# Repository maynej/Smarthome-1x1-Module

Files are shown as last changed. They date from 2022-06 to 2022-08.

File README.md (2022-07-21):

# Smarthome-1x1-Module

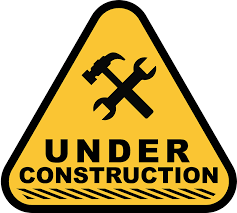
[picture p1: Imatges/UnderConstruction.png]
Maqueta de Casa Domótica Educativa en construcció 

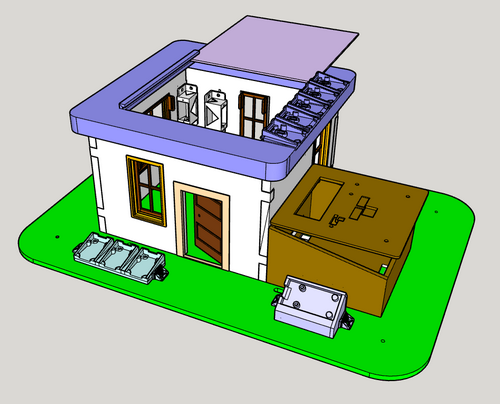
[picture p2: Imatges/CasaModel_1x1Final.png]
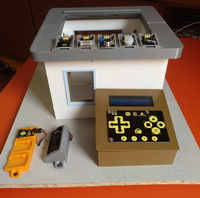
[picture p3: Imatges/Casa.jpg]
   

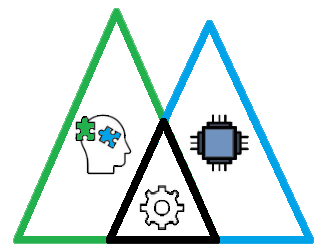
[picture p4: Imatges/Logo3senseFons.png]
Realitzada per [Jordi Mayné](https://github.com/maynej) des de Mechatronic Study jordi.mayne@mechatronicstudy.com 

L'objectiu es construir una casa modular abstreta del projecte del Parc mediambiental educatiu on permet provar diferents tecnologies de control aplicant la domòtica, gestionant el medi ambient i mesurant paràmetres de la natura.

Tota la [documentació es pot trobar en PDF](https://github.com/maynej/Smarthome-1x1-Module/tree/main/DOC). També estarà en llengua castellana (en preparació).

STL per imprimir [aquí](https://github.com/maynej/Smarthome-1x1-Module/tree/main/STL).

## Casa 3D 
  
Descripció         | Imatge          | Arxiu         
------------- | ------------- | ------------- 
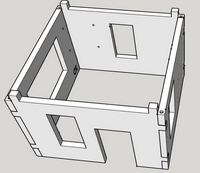
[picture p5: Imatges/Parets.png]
Parets | | [Parets](STL/Parets)
Finestres | | [Finestres](STL/Finestres)
Porta | | [Porta](STL/Porta)
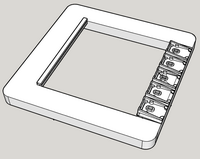
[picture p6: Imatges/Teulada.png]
Teulada | | [Teulada](STL/Teulada)
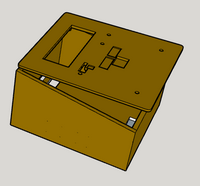
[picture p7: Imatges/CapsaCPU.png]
Capsa Control | | [Capsa CPU](STL/CPU)
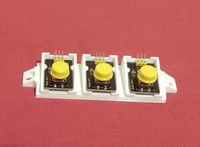
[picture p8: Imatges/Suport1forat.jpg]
Suport 1 forat | | [Suport 1 forat](STL/SuportsModuls/Suport1forat)
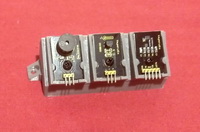
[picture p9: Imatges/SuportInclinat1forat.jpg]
Suport Inclinat 1 forat | | [Suport Inclinat 1 forat](STL/SuportsModuls/SuportInclinat1forat)
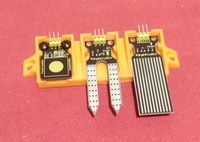
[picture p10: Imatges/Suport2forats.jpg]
Suport 2 forats | | [Suport 2 forats](STL/SuportsModuls/Suport2forats)
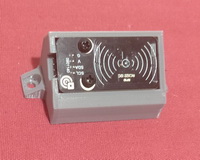
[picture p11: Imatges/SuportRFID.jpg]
Suport RFID | | [RFID](STL/SuportsModuls/SuportRFID.stl)

## Base de fusta  
  
Descripció         | Imatge          | Arxiu         
------------- | ------------- | ------------- 
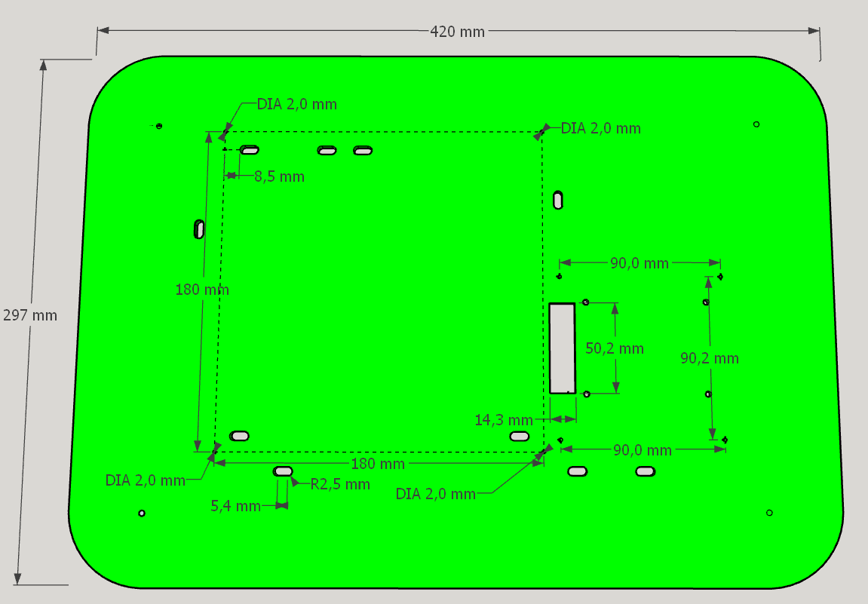
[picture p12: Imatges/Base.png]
Base fusta | | [Base fusta](Base/)

## Parets sólides
Descripció         | Imatge          | Arxiu         
------------- | ------------- | ------------- 
Parets | | [Parets](STL/Parets/ParetsSolidesOpcionals)

Creative Commons Attribution-NoComercial-ShareAlike 4.0 International (CC BY-NC-SA 4.0)  

## QR
QR Code generator

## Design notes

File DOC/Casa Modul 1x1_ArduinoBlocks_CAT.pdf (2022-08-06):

1 | JORDI MAYNE ‐ 2022

# Casa domòtica educativa

## Objectiu

Construir una maqueta d’una casa educativa per aplicar domòtica, mesurant paràmetres de la natura.

## Dinàmica educativa

- Es pretén que sigui Obert, Didàctic, Evolutiu, Modulable, Flexible, i de baix cost.
- La construcció de la maqueta està preparada per ser impresa en una impressora 3D convencional, però, es pot fer amb fusta o cartró ploma, i al ser modular permet adaptar‐la a les necessitats.
- Permet gestionar els llums a LED de colors, Sensors, Actuadors i altres elements electrònics per tal de fer la part de domòtica que es controlarà amb una placa ESP32 STEAMakers, encara que es pot fer amb una Arduino, Microbit o fins hi tot amb una Raspberry ...

Com es podrà veure en tota la descripció, es vol que es puguin explorar el màxim tipus d’elements i tecnologies.

## Descripció general

### Sensórica Externa

Mesurant el nostre entorn, com la Temperatura i Humitat ambient, Pressió atmosfèrica, Llum, Raigs ultraviolats, Qualitat del aire.

### Casa Domòtica

Control del màxim d’elements fent servir tecnologies diverses com la Llum, Accés, Ventilació, Calefacció, Motors.
Es pot detectar Gas, Foc, Llum, So, Humitat, Temperatura, Presencia (PIR, IR), Alarma.

### Comunicacions

Dintre d’un entorn sostenible les comunicacions son necessàries si es gestionen be com Bluetooth, Wifi, RFID

## Realització del projecte

- Descripció de cada part de la maqueta.
- Selecció de materials i components.
- Desenvolupament de cada part.
- Construcció de la maqueta.
- Composició del control electrònic.
- Control global de la maqueta.

### Maqueta

La maqueta es una abstracció d’una maqueta molt més gran, creada per poder aplicar molts més elements i controls, però, dintre del mon educatiu demanava una casa més apropiada, per el temps disponible durant el curs, per aplicar els conceptes i portar‐los a terme. Al ser modular permet adaptar‐la a les necessitats més escaients.

Casa Sostenible i Domòtica • Les noves cases han de ser sostenibles, aprofitant totes les energies renovables que estiguin a l’abast

(eòlica, tèrmica, solar, hidràulica, geotèrmica).
- Recollida de l’aigua pluvial per reaprofitar‐la.
- Aprofitament de la llum solar.
- Aïllament.
- Control de residus.
- Control domòtic.

En aquesta maqueta per espai no es poden portar a terme tots aquest punts, però, algun d’ells si.

### Disseny de la maqueta de la casa

Per fer aquesta maqueta he utilitzat un projecte molt més gran https://github.com/maynej/Smart‐Home i n’he fet una abstracció, ja que la seva modularitat ho permet, utilitzant un mòdul 1x1 permet tenir una maqueta tipus DIN A3 i a una escala 1:24 permet incloure i manipular els actuadors i sensors.

Es poden escollir de la casa gran les parets amb els formats que es vulguin, per cobrir les necessitats per aplicar la tecnologia. Es poden imprimir en una impressora 3D convencional de 220x220mm. Aquestes parets es poden modificar per adaptar‐les a un disseny propi, per això es mostren també parets sense cap porta ni finestra per si es vol desenvolupar un disseny propi. Les parets incorporen les fixacions dels actuadors a les portes, finestres, i en la teulada l’allotjament dels llums tant interiors com exteriors i en aquesta maqueta el suport per fixar els sensors. La teulada es pot treure molt fàcilment per manipular els components.

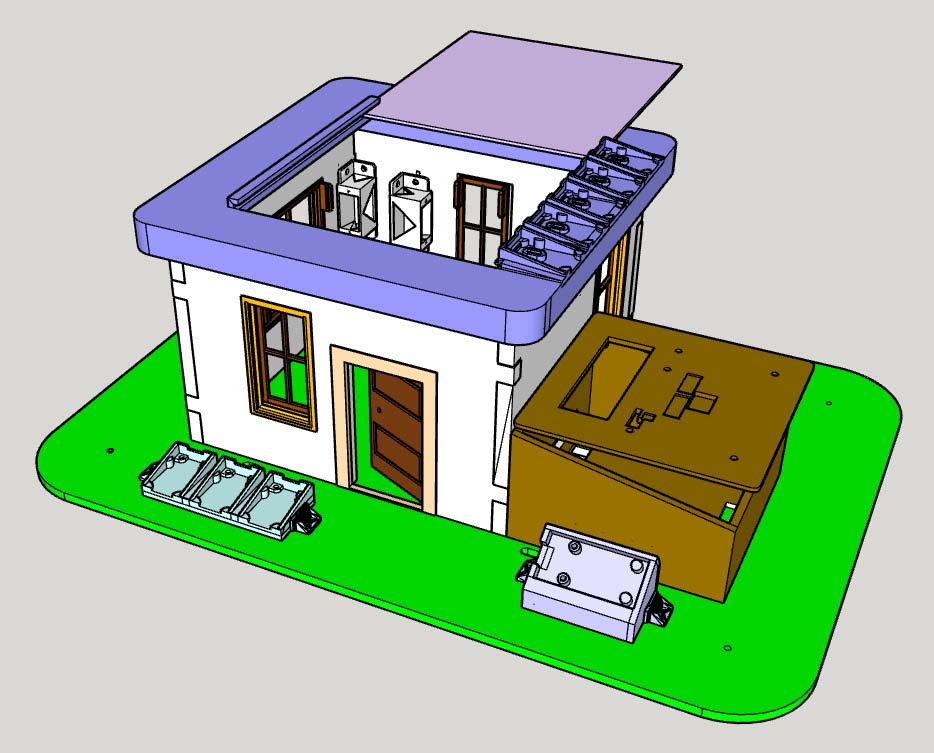
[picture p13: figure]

Altres suports com el mòdul de RFID, polsadors i d’altres sensors addicionals es poden fixar en la base, així com l’armari exterior (com si fos per guardar la fusta) que inclou la placa ESP32 STEAMakers, o Arduino Uno, un visualitzador LCD i un teclat tàctil.

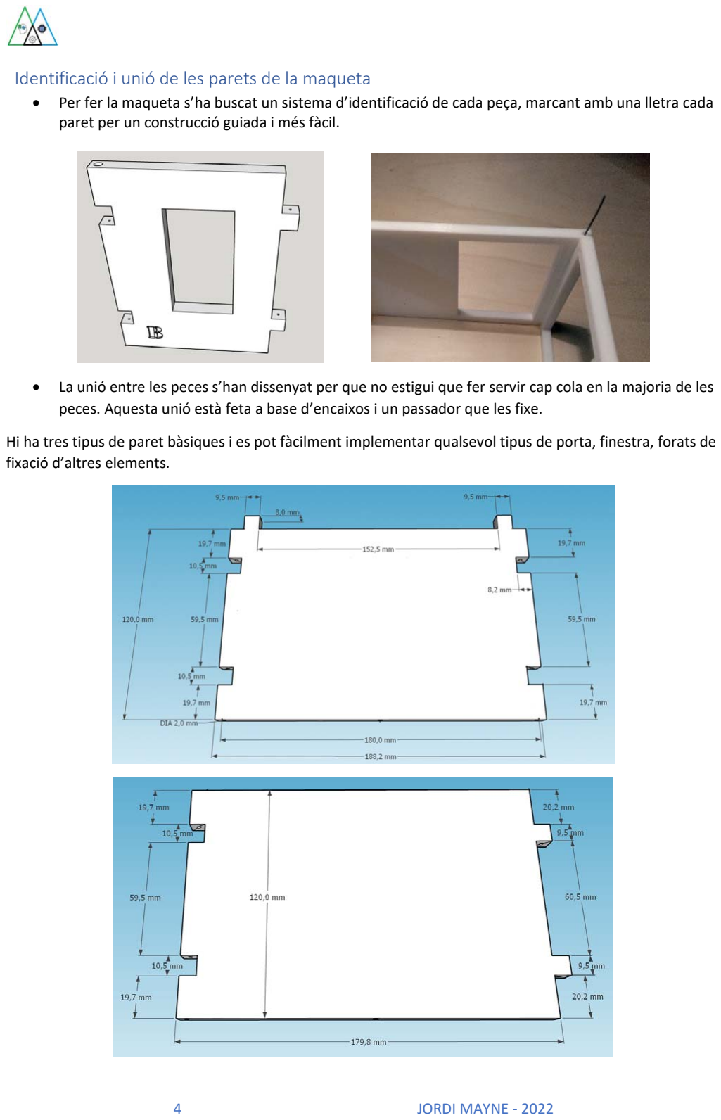
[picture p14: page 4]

### Identificació i unió de les parets de la maqueta

- Per fer la maqueta s’ha buscat un sistema d’identificació de cada peça, marcant amb una lletra cada paret per un construcció guiada i més fàcil.
- La unió entre les peces s’han dissenyat per que no estigui que fer servir cap cola en la majoria de les peces. Aquesta unió està feta a base d’encaixos i un passador que les fixe.

Hi ha tres tipus de paret bàsiques i es pot fàcilment implementar qualsevol tipus de porta, finestra, forats de fixació d’altres elements.

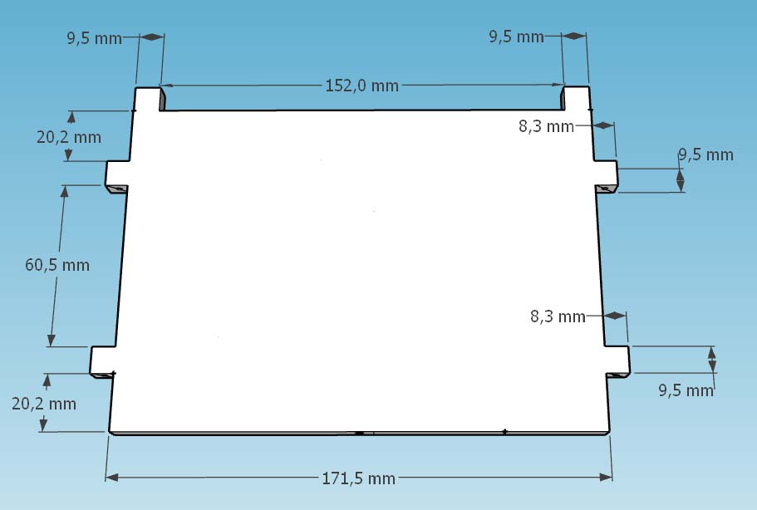
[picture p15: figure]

En aquest cas farem servir les parets A1, C1, T1 i H1.

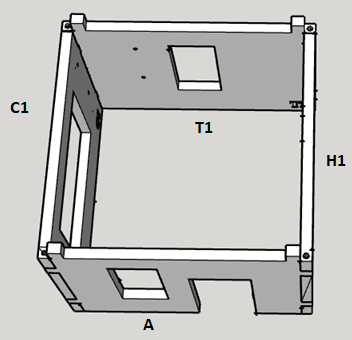
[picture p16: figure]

Alternativament la paret T1 es pot substituir per la T1_Fan que incorpora l’allotjament del ventilador de 40x40mm per simular la ventilació de la casa.

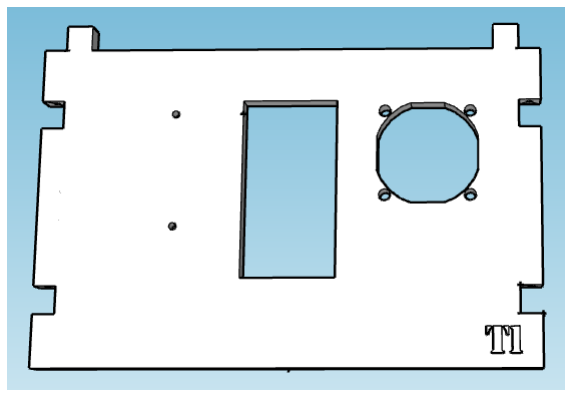
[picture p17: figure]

## Descripció de l’exterior Casa

- La casa es de tipus unifamiliar amb un sol habitacle amb una teulada amb sostre practicable permet que sigui accessible per manipular els diferents components.
- Porta d’accés a la casa. Timbre, i accés amb identificació per RFID.
- Il∙luminació a LED a color per l’exterior, amb detecció de presencia i de llum diürna.
- Els sensors en la teulada.

### Accés a la casa

Com qualsevol casa un polsador servirà de timbre, també un lector RFID identificarà i permetrà obrir la porta amb una targeta RFID vàlida.

- Timbre de trucada amb polsador (KS0029
- Lector RFID RC522 I2C (KS0205V2
- Porta motoritzada amb un servomotor SG90 (KS0194

### Il∙luminació de l’exterior de la casa

Llums LED de color WS2812 i un sensor de proximitat PIR (KS0052amb sensor de llum diürna per il∙luminar la porta d’entrada o les permanents de nit des del control central.

## Descripció de l’interior de la Casa

- Sistema d’alarma
- Control de llum LED individualitzat amb control d’intensitat de llum i de color
- Control finestres batents motoritzades
- Control de porta motoritzada
- Control Ventilació

### Llum interior de la Casa

El control de la llum es fa tant manualment, com automàtic mitjan sensors.

- LED + Sensor de moviment (KS0052
- LED + Polsador (KS0029
- LED + Sensor de veu (KS0035)
- LED + Sensor de llum ambiental TEMT6000 (KS0244 | o LDR (KS0028

### Ventilació

Un ventilador mou l’aire per tota la casa

- Temperatura LM35 (KS0022 | o DS18B20 (KS0023
- Humitat i Temperatura DTH11 (KS0034 | o SHT31 (KS0348
- Ventilador (KS0168

### Sistema d’Alarma

Un sistema integrat d’alarma contra intrusió, foc, gas

- Sensor de vibració (KS0037

- Sensor de cops (KS0024
- Sensor de gas MQ‐2 (KS0040
- Sensor flama (KS0036
- Brunzidor passiu (KS0019

### Pantalla i Teclat de control

- Pantalla LCD 2x16 I2C (KS0061, on es podrà mostrar dades de la casa. També es podrà tindre accés des de un telèfon o “tablet”.
- Teclat tàctil capacitiu (KS0210 | KS0260
- Monitorització de dades dels sensors.
- Monitorització del control d’accés a la casa, sistema de seguretat.
- Monitorització de la ventilació.

### Sistema central de control

El control també està pensat obert, si no ja no seria didàctic. Encara que es farà servir una ESP32 STEAMakers amb format Arduino UNO, està adaptat per utilitzar Arduino UNO, o Microbit.

El software d’aquestes plataformes permeten utilitzar diferents llenguatges de programació, Scratch, C++ per Arduino, ArduinoBlocks.

- Arduino UNO, STEAMakers ESP32: Arduino Blocks, C++

### Alimentació

La maqueta al igual que moltes cases actuals que generen energia per el autoconsum, necessiten també d’energia elèctrica addicional. La maqueta pot tindre generador d’energia que poden carregar unes petites bateries, com pot ser una plataforma de cèl∙lules solar però, normalment es farà servir una font d’energia a xarxa.

Plantejament de la casa Aquesta construcció es minimalista, però permet aplicar diferents tecnologies per el control i es poden canviar

o afegir sensors.

## Plantejament del control

- El control es podrà fer a través de tasques individualitzades o agrupades per anar progressant en el coneixement dels dispositius junt amb el visualitzador i teclat per mostrar el seus funcionaments.
- Moltes tasques es faran simulades intentant reproduir al màxim el seu funcionament real.
- Els sensors bàsics utilitzats es podran canviar per altres similars o més sofisticats, està previst que el seu accés i cablejat ho permeti.

### Maqueta de la casa

La casa s’ha format amb les següents peces, A, C1, T1, H1

### Finestres batents i Portes motoritzades

- Les finestres son batents amb moviment a través d’un servo‐motor.
- Les portes també estan motoritzades a través d’un servo‐motor.
- Totes les portes i finestres tenen els ancoratges en la paret per posar un servo‐motor.

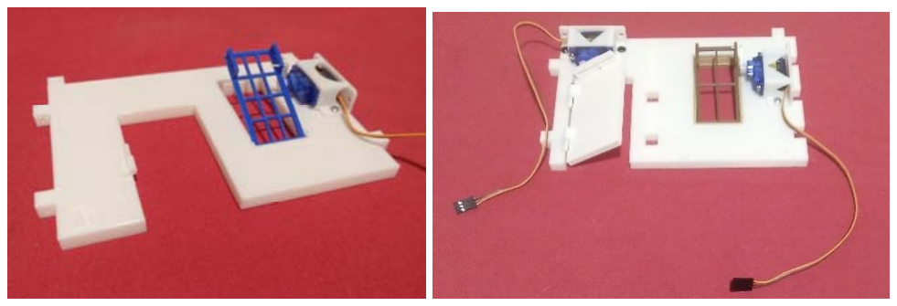
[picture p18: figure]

### Teulada

La teulada està formada per una sola peça, encara que es fa impresa amb dues parts si s’utilitza una base de 220x220mm. La base, per la part de sota, incorpora uns espais on aniran instal∙lades les llums externes envoltant la casa, així com la interna a LED a color del tipus tira de 8 LED WS2812. Amb sols tres fils es poden controlar tots els LED.

En la part superior es col∙locaran els sensors en uns suports, també permet posar una coberta semitransparent, per simular una entrada de llum solar, i per poder mesurar temperatura interior i exterior del habitacle.

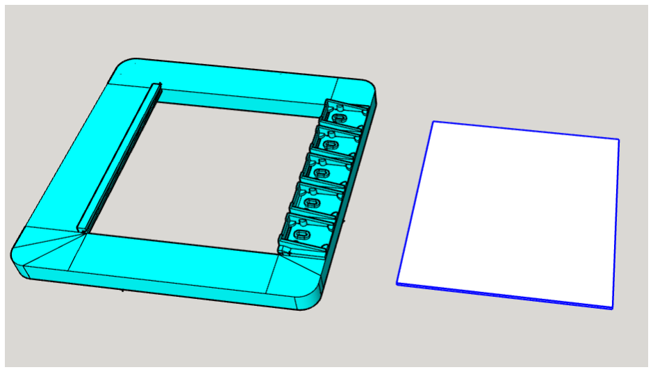
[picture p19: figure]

Teulada i coberta

### Subjecció de les parets a la base de fusta

Totes les parets tenen forats per ancorar‐les a la base de fusta de la casa.

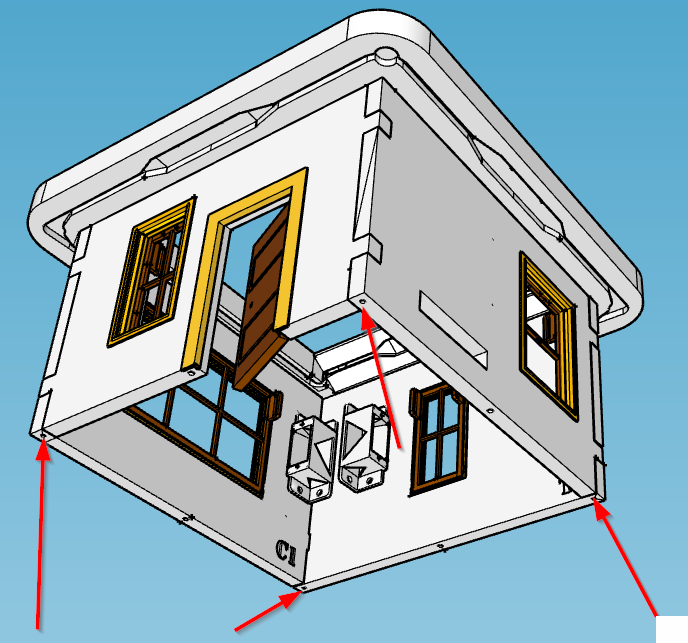
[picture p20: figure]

La base de fusta pot ser de 5mm, s’acota tota la maqueta i es mecanitza o es pot fer amb tall làser, s’inclou el fitxer svg. Es pot afegir en el dibuix svg el logo o nom del usuari.

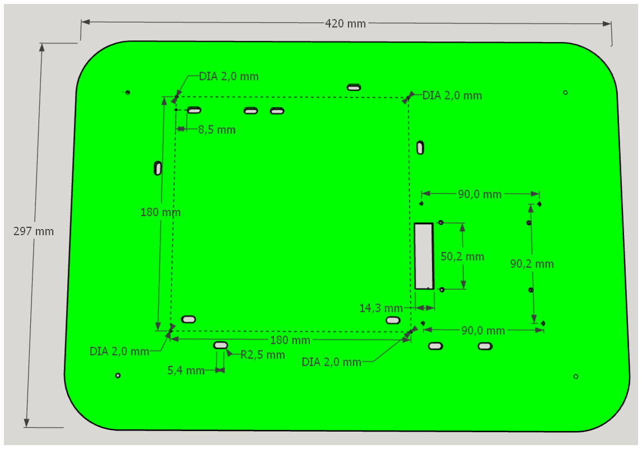
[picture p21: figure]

Els quatre punts de la casa fixen l’estructura, els forats ovalats son per el pas dels fils dels servomotors per sota de la base fins el pas rectangular per entrar en la capsa de control central.

Una vegada fixada l’estructura de la casa, es pot continuar treballant amb la resta de la casa, posant els marcs de les portes, finestres, ....

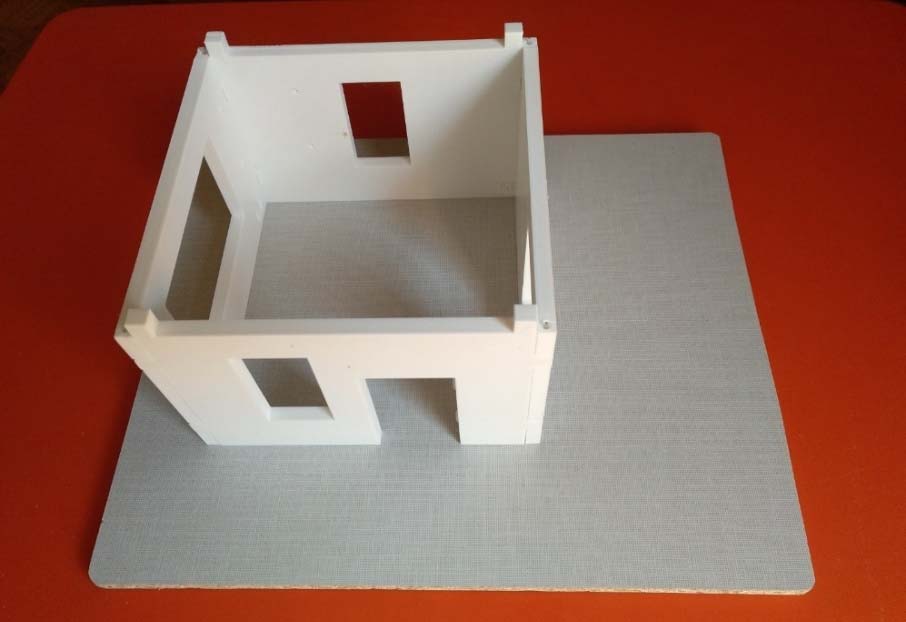
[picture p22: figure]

En el tauler base de la casa es fixen quatre separadors de goma de 20 mm d’alçada, suficient per deixar passar els cables.

La teulada semi‐transparent es pot fer amb full de plàstic a partir de 0,75mm de gruix per que tingui una mica de consistència. També les finestres també, però amb plàstic transparent.

### Muntatge electrònic

Per començar amb el sistema electrònic es pot fer el connexionat dels llums de LED multicolor WS2812B a la part inferior de la teulada. Es fan servir tres fils (Positiu 5V, negatiu (gnd) i dades) amb tres color ben diferenciats per no fer cap errada, es poden fixar els fils trenant en forma d’espiral i es poden subjectar amb tub termo‐retràctil.

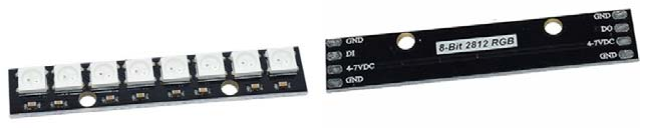
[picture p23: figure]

Les soldadures han d’estar ben fetes i que no es facin curt‐circuits en les connexions, cal fer una revisió visual i una prova de funcionament abans de col∙locar‐lo en les guies de la teulada.

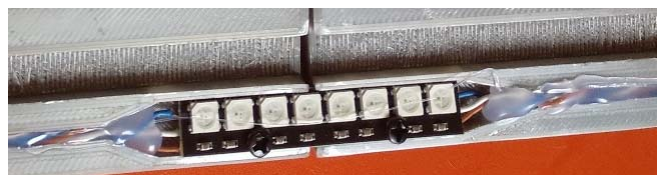
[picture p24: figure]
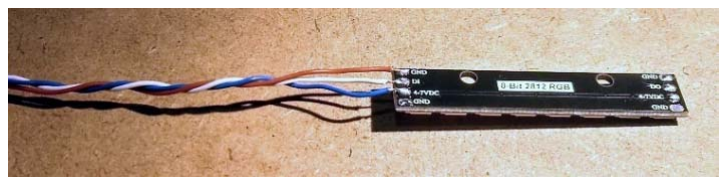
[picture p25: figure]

Una vegada que es te el cablejat fet i revisat, es col∙loca en la guia corresponent i es fixe amb una mica de cola termo‐fusible.

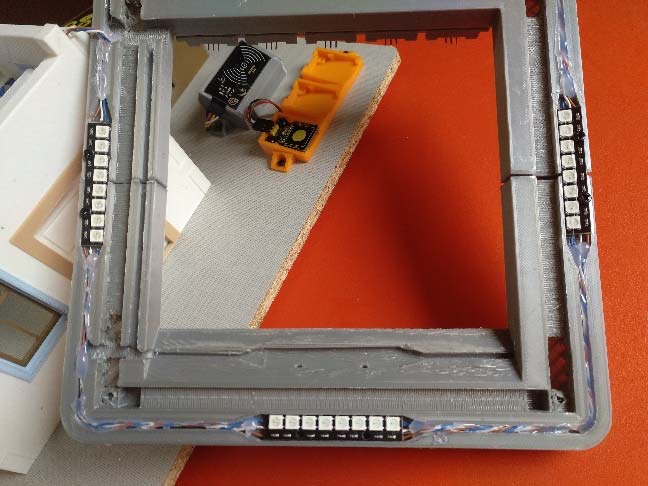
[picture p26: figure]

## Plantejament del control central

Tal com s’ha exposat al principi d’aquest document, el control central es podrà fer a través de tasques individualitzades o agrupades per facilitar una programació, primerament per parts per facilitar l’ús de un hardware senzill. D’aquesta manera es poden establir funcionalitats bàsiques fins les més complexes, i funcionalitats futures.

### Control central

El control central està plantejat utilitzant la placa STEAMakers, basada amb un controlador ESP32 Plus, compatible amb el format Arduino UNO, fabricada per Keyestudio, i ha estat desenvolupada conjuntament amb l’equip de Innova Didàctic.

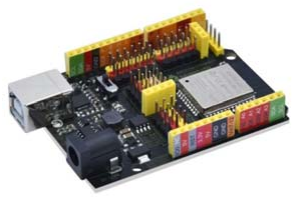
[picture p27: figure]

La primera cosa que sorprèn al veure aquesta placa es la quantitat de pins disponibles a banda dels connectors que incorporen totes les plaques Arduino, que corresponen a 12 entrades/sortides digitals, 4 entrades analògiques, 1 canal sèrie Tx/Rx i 5 connectors I2C, tots amb alimentació, i el sòcol per memòries µSD en la part posterior.

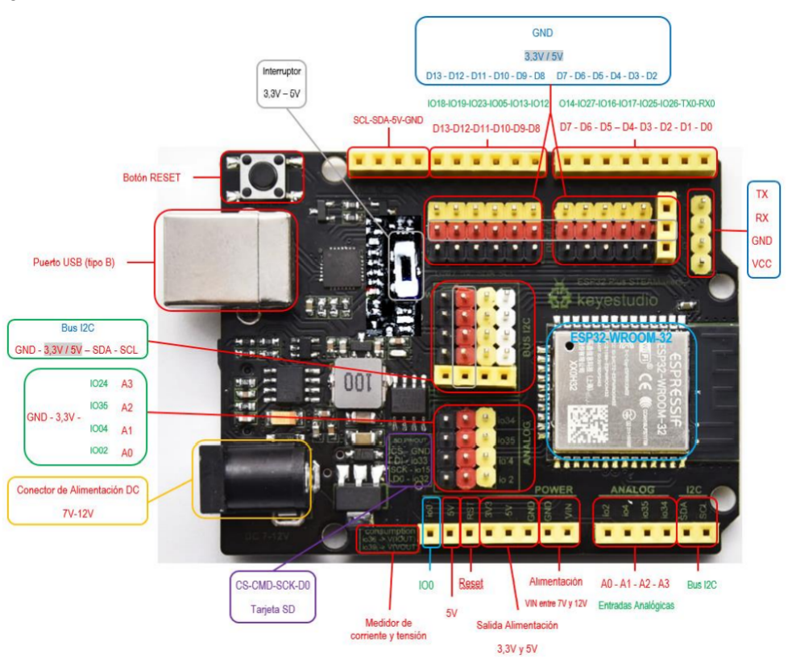
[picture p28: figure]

Però hi ha més detalls, un commutador de 3.3V a 5V per alguns pins d’alimentació i un shunt en l’alimentació per mesurar el corrent.

El processador ESP32 de 32 bit, és un sistema de doble nucli amb dues CPU (Unitat Central de Procés) amb arquitectura Harvard Xtensa LX6. Tota la memòria interna, la memòria externa i els perifèrics es troben en el bus de dades i/o en el bus d'instruccions d'aquestes CPU. Amb algunes excepcions menors, l'assignació d'adreces de les dues CPU és simètrica, el que significa que utilitzen les mateixes adreces per accedir a la mateixa memòria. Diversos perifèrics del sistema poden accedir a la memòria interna mitjançant DMA.
Les dues CPU s'anomenen "PRO_CPU" (per a computar els protocol) i "APP_CPU" (per computar l’aplicació), però, per a la majoria de propòsits, les dues CPU són utilitzables per qualsevol tasca. Més endavant es veurà en profunditat l’estructura del nucli.

### Tasques individualitzades

En aquest apartat es mostraran les tasques que es poden realitzar per treballar‐les individualment i el seu hardware associat.

### Control dels llums de la casa

Els llums de la casa son de LED del tipus RGB WS2812 (anomenats Neopixel) en format de tira de 8 LED, es poden encendre individualment amb el color i amb la intensitat de llum que es vulgui (per programa), i només amb tres fils. Això permet fer escenaris diferents de l’exterior de la casa, hi han quatre grups, una per cada paret. També hi ha una tira en el interior per poder crear un ambient de llum més càlida o més blanca. Aquets llums poden ser automàtics com el cas dels llums exteriors, amb un sensor de llum ambient, o a través de polsadors mecànics o tàctils. També es podrà comandar algun llum amb sensor de presencia. Per tant es una instal∙lació per un control molt flexible.

Primer de tot cal enumerar cada punt de llum de la casa per preparar la programació. Com que son grups de 8 LED i el primer correspon a la façana frontal (L1, L2, L3, L4, L5, L6, L7, L8). Si es fan servir més grups seran: L9‐L16 per la façana esquerra, L17‐L24 façana posterior, L25‐32 façana dreta i L33‐40 per la llum interior. També els polsadors, per encendre i apagar el llums interiors LINT i els llums exteriors LEXT.

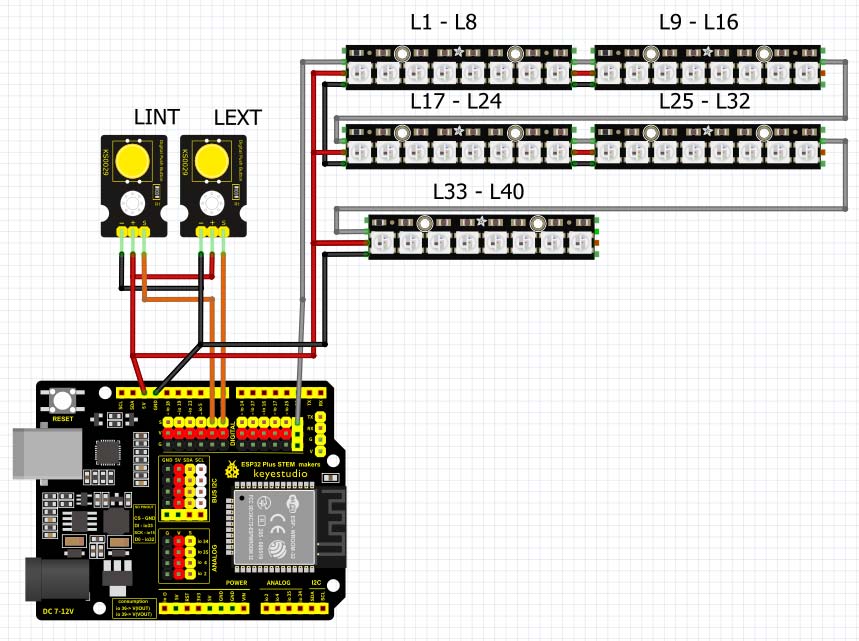
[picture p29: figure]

Es pot crear una taula per tenir tots els components:

Descripció | Actuador | Pin STEAMakers | Polsador | Pin STEAMakers
LED frontal | L1‐L8 | io12 | LEXT | io26
LED esquerra | L9‐L16 | io12 | LEXT | io26
LED posterior | L17‐L24 | io12 | LEXT | io26
LED dreta | L25‐L32 | io12 | LEXT | io26
LED interior | L33‐L40 | io13 | LINT | io26

Es a dir, es fan servir dos pins per els polsadors io12, io13, i per tots els LED només el pin io26. Ara afegirem el control de servos de porta i finestres.

### Control dels servos Porta i finestres

Els servos obren o tanquen porta i finestres, també cal enumerar cada un. Porta D1, finestra frontal W1, finestra esquerra W2, finestra posterior W3, finestra dreta W4.

Es pot crear una taula per tenir tots els components connectats a la placa STEAMakers:

Descripció | Actuador | Pin STEAMakers | Polsador | Pin STEAMakers
LED frontal | L1‐L8 | io12 | LEXT | io26
LED esquerra | L9‐L16 | io12 | LEXT | io26
LED posterior | L17‐L24 | io12 | LEXT | io26
LED dreta | L25‐L32 | io12 | LEXT | io26
LED interior | L33‐L40 | io13 | LINT | io26
Servo Porta frontal | S_D1 | io14 | D1 | io19
Servo Finestra frontal | S_W1 | io27 | W1 | io23
Servo Finestra esquerra | S_W2 | Io16 | W2 | io05
Servo Finestra posterior | S_W3 | io17 | W3 | io13
Servo Finestra dreta | S_W4 | io25 | W4 | io12
LED frontal | L1‐L8 | io26 | LEXT | io18
LED esquerra | L9‐L16 | io26 | LEXT | io18
LED posterior | L17‐L24 | io26 | LEXT | io18
LED dreta | L25‐L32 | io26 | LEXT | io18
LED interior | L33‐L40 | io26 | LINT | ?

Què ha passat? ..., que ens hem connectat tots els components menys un, el polsador de activació de la llum interior (LINT), no queda cap entrada/sortida digital lliure...

Encara que tots els LED tant exteriors com interiors només fan servir un sol pin (io26), els demés 6 polsadors ens ocupen la totalitat d’entrades digitals i encara ens en manca un.

Les solucions possibles son diverses, o fer servir menys finestres o afegir circuits que ens resoldran aquest problema.

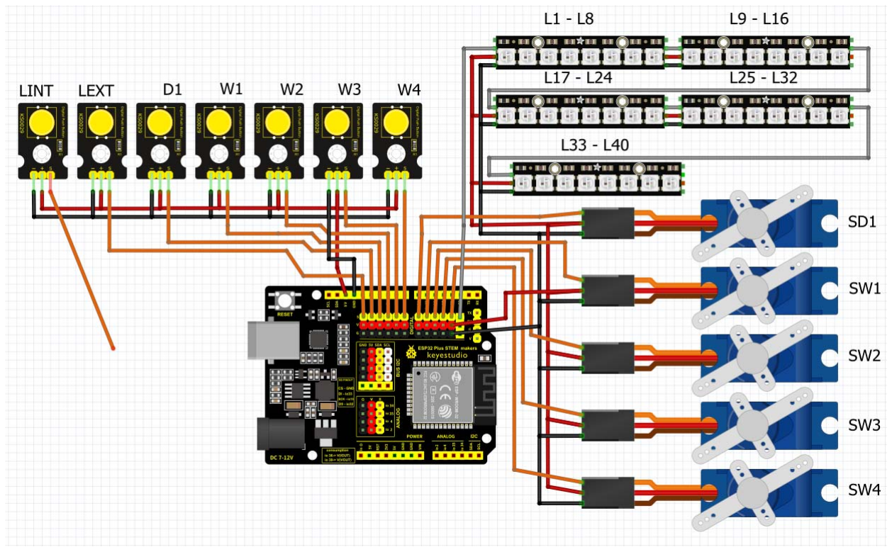
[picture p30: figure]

### Expansió d’entrades i sortides en un Arduino

Com que es necessiten moltes entrades de polsadors, cal plantejar utilitzar plaques Arduino que tenen més entrades/sortides o varies plaques Arduino connectades entre sí, cosa que no es la solució més adequada. Es millor col∙locar un expansor d’entrades/sortides amb un mòdul expansor via dos fils I2C.

PCF8574 es un mòdul expansor de 8 canals digitals de entrada/sortida amb comunicació I2C cap el microcontrolador, per defecte al alimentar el circuit son entrades digitals (P0 a P7), funciona entre 2,5 i 6V, incorpora 3 ponts (A0 a A2) per configurar l’adreça I2C (des de 0x20 a 0x27 si estan a ‐), te dos pins de comunicació típiques de I2C, SDA (dades), SCL (rellotge) i alimentació.

Es troben diferents formats de mòdul, aquest de color blau permet
expandir a més plaques PCF8574 encadenant diversos mòduls per tenir
encara més entrades/sortides digitals.

Cada nou mòdul addicional es configura amb una adreça I2C diferent, es selecciona amb els ponts de cada mòdul.

Aquest mòdul amb A0, A1 i A2 amb el pont a 0, correspon a l’adreça 0x20

Es poden encadenar diversos mòduls PCF8574 de la manera següent i canviant un pont d’adreçes.

Així quedarà el muntatge, alliberant 6 pins d’entrada de la placa STEAMakers, i encara ens queden dos pins lliures en el mòdul PCF8574.

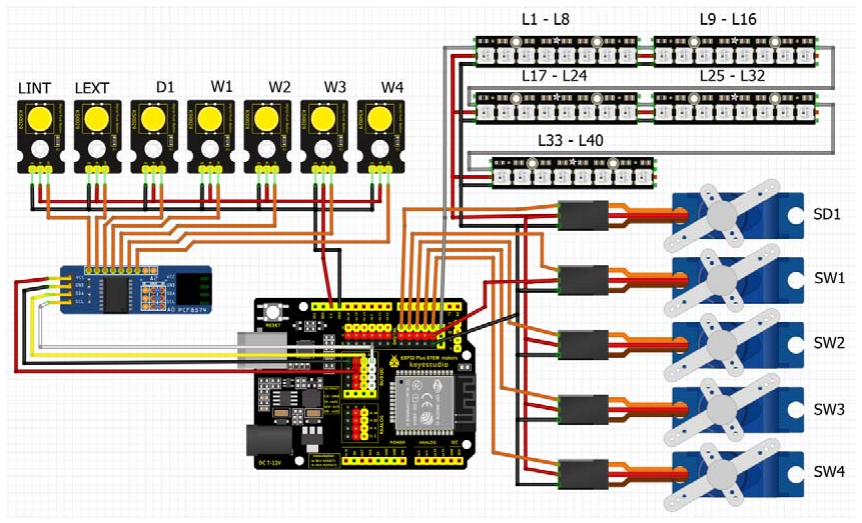
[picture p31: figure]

Si es volen alliberar més pins es pot fer afegint un altre mòdul I2C PCA9685 que suporta fins a 16 servomotors controlats via I2C. Disposa de pins per connectar adequadament els servomotors, les adreces I2C van des de 0x40 fins a 0x7F soldant els ponts (A0...A5), entrega 16 sortides PWM de 12 bits, s’alimenta a 5V, i les línies SDA i SCL de I2C son compatibles 3V3 o 5V.

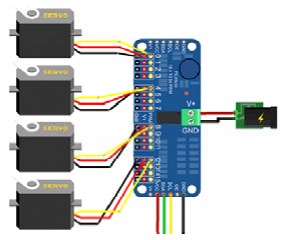
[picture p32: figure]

A banda de alliberar pins, s’ha de tenir en compte que els servomotors tenen
un consum “elevat”, sobre els 200mA que circula per dintre del circuit processador de Arduino i si a més alliberem aquesta corrent, sempre es millor, en aquest cas podem programar que les finestres s’obrin a la vegada, per airejar la casa, o tancar‐les per evitar que entri fred, 200mA multiplicat per 4 finestres son 0,8A que circularien per el circuit.

Servomotors SG90: Un servomotor, anomenat també servo, és un motor DC amb la capacitat de posar el seu eix en una posició o angle determinat, internament té una caixa d’engranatges reductora que fa augmentar el parell motor i redueix la velocitat, un
potenciòmetre està encarregat de sensar la posició de l’eix i junt amb una electrònica
formen un control de llaç tancat.

Hi ha diferents tipus de servo‐motors, el més utilitzat es el SG90 que es suficient per la majoria d’aplicacions. Funciona entre 3 i 7.2V, te un parell motor entre 1 i 1.6 kg/cm. Altres tenen parell motor més grans arribant fins a 15 kg/cm.

Utilitzant el mòdul PCA9685 allibera 5 pins més, digitals. Així queda l’esquema electric.

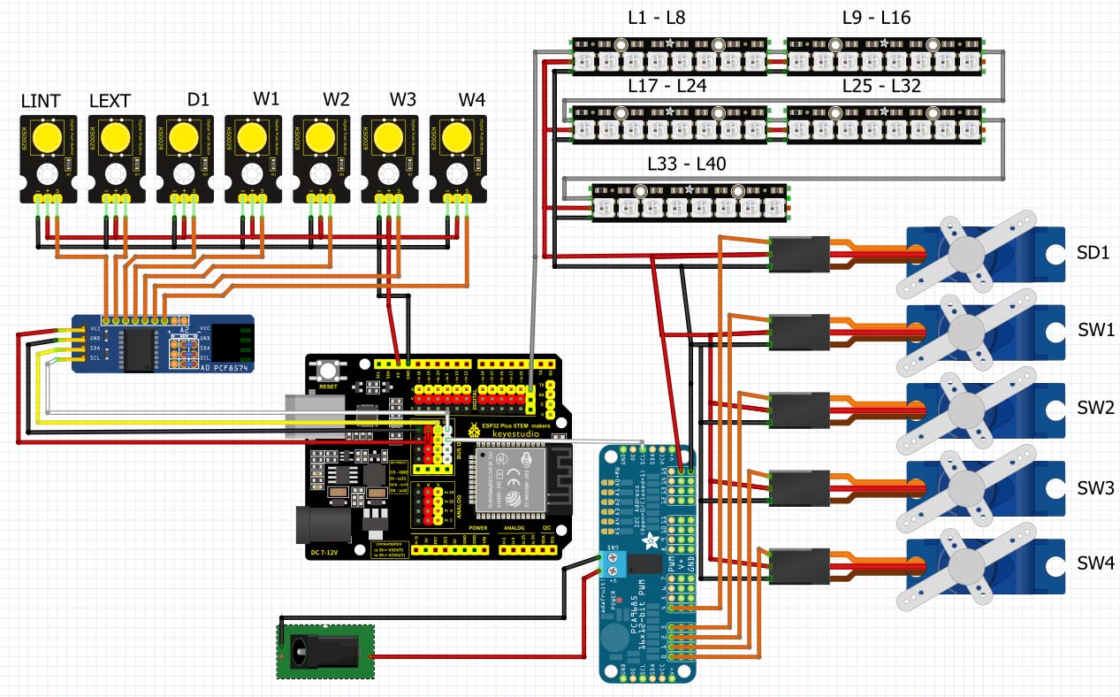
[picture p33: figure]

Anem afegint més components, visualitzador i teclat. Una vegada més s’ha escollit dos mòduls amb comunicació I2C visualitzador LCD 1602 (KS0061 i teclat tàctil TTP229 (KS0260.

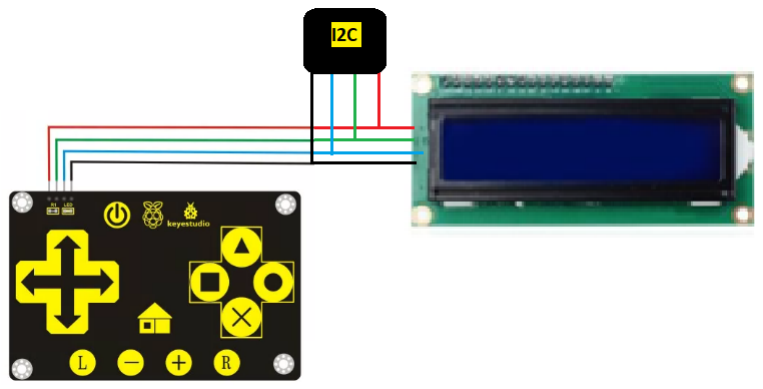
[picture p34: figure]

Amb aquests components no es fa servir cap pin digital

Per allotjar els mòduls STEAMakers, PCF8574 i PCA9685, així com el visualitzador LCD 1602 i el teclat TTP229, s’ha creat un armari per l’exterior de la casa. Es podrà fer servir tots aquests mòduls o no, però l’armari està preparat. La tapa pot allotjar el teclat TTP229 (KS0210 connector rectangular 6 pin i 3 forats de subjecció KS0260 connector 4 pin en línia més útil per fer servir els cables I2C i 4 forats de subjeccióla diferencia entre elles es el forats dels ancoratges i el tipus de connector, però la funcionalitat es la mateixa.

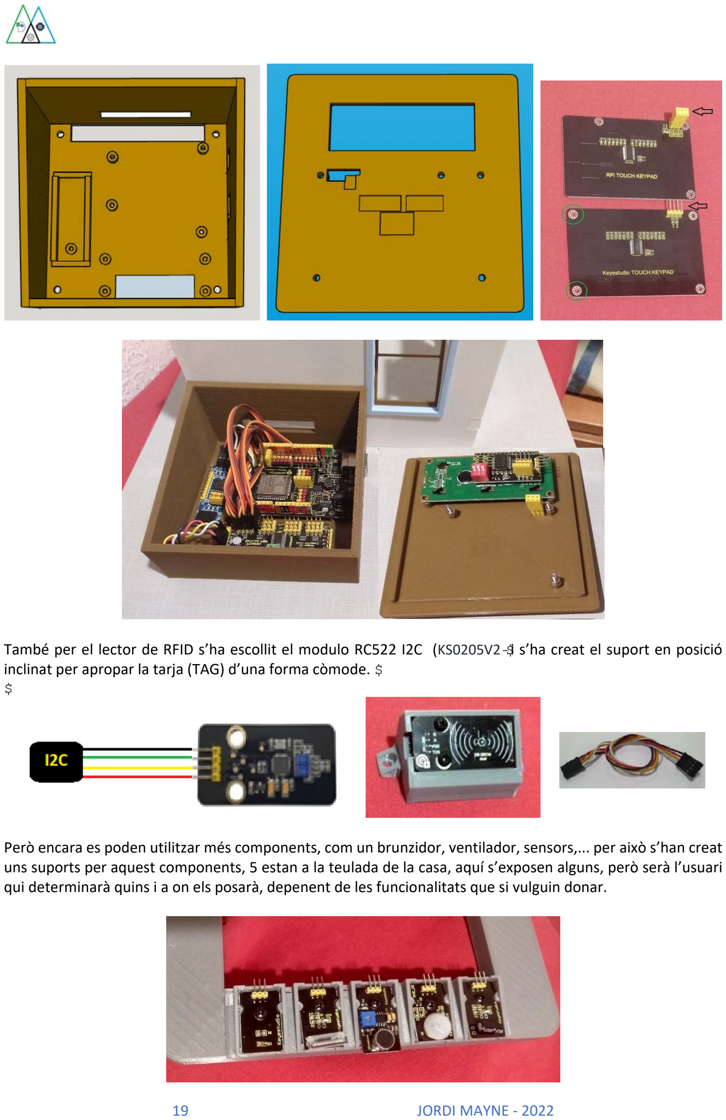
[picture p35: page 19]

També per el lector de RFID s’ha escollit el modulo RC522 I2C (KS0205V2i s’ha creat el suport en posició inclinat per apropar la tarja (TAG) d’una forma còmode.

Però encara es poden utilitzar més components, com un brunzidor, ventilador, sensors,... per això s’han creat uns suports per aquest components, 5 estan a la teulada de la casa, aquí s’exposen alguns, però serà l’usuari qui determinarà quins i a on els posarà, depenent de les funcionalitats que si vulguin donar.

Aquí es poden veure els diferents tipus de suports fins a 3 components, i en el repositori https://github.com/maynej/Smarthome‐1x1‐Module es poden trobar de 2, 3 i 4 components cada un. Keyestudio facilita bastant amb la uniformitat física de les plaques de cada component.

Brunzidor (KS0019(Buzzer en anglès) es un transductor electroacústic que produeix un so com si fos un altaveu, encara que en una qualitat menor. Serveix com un mecanisme
de senyalització o avis, i si s’utilitza en múltiples sistemes es pot que emeti sons diferents
segons la freqüència aplicada.

Pot servir, com a timbre de la porta, alarma de intrusió, o un altre tipus d’alarma dels diferents sensors que usem.

Sensors de presencia o moviment, hi ha diverses maneres de detectar “presencia”, el primer es conèixer els diferents tipus i veure que volem detectar, i a on. Es pot fer amb IR, ultrasons, PIR, làser, radar, mecànic, so.

IR consisteixen en un emissor i un receptor de IR actuen per rebot (KS0051 es bastant
direccional 35 graus, l’abast es de 2 a 40 cm (ajustable amb potenciòmetres), la
influencia dels rajos del sol van en contra.

Ultrasons, es tracta d’emetre un so a 40kHz (no audible per els humans) i rebre per rebot aquest so, mesurant el temps que tarda es pot determinar la distancia fins l’objecte. No es tan direccional (15 graus), l’abast es gran, entre 2 i 5m. (KS0206
Les aplicacions en una casa es poden ajustar gairebé a mesurar el nivell de líquid en
un dipòsit.

PIR (InfraRoig Passiu) es d’un material piroelèctric que canvia les seves propietats segons les emissions IR captades que passen a través d’una lent de Fresnel, que es una semiesfera que concentra aquestes emissions en un sol punt. Detecten objectes que emeten calor (com els cos humà i animals) l’abast es més gran fins a 3‐ 4 metres a 25ºC, i no es direccional 100 graus. Es el que farem servir per detectar quan una persona s’acosta a la porta i encenem el llum de la porta. (KS0052

Làser, realment ens referim als anomenats TOF (Time of Flight), son de darrera generació i mesuren el temps en que un pols de làser surt del emissor, rebota en el objecte i torna al receptor, es conta el temps i s’aconsegueix mesurar la distància amb molta precisió. Es molt direccional, l’abast pot arribar, depenent del model, fins a 2m (VL53L0X). Detecta qualsevol tipus d’objecte. En una casa el podríem fer servir per detectar que una persona s’acosta al intèrfon i es posa el sistema en marxa (per exemple, el vídeo porter).

Mecànic, podria ser un microruptor sota una fusta o en una porta(KS0021

Sensor de so, podem utilitzar el so de la veu per activar un llum, (KS0035)

Sensors de llum, hi ha una diversitat de sensors de llum, aquí ens centrem en el més bàsic basat en una LDR (Resistència que Depèn de la Llum) (KS0028 i el més complert i aconsellable, el sensor de llum ambiental TEMT6000 (KS0244.

El sensor TEMT6000 que només detecta la presència amalgamada de llum amb longituds d'ona en el rang de 390 a 700 nm, en altres paraules, no captarà infrarojos, ultraviolats o cap altra llum que no puguem veure directament. Es un sensor analògic que és sensible a l'espectre visible i es fa servir en molts aparells com smartphones, “tablets”, càmeres i està adaptat a la resposta de l’ull humà envers la llum. Te un angle de 60 graus i s’alimenta a 5V.
Aquí hi ha una taula de la il∙luminació típica de fonts comunes de llum visible:
Il∙luminació | Superfícies il∙luminades per
0.0001 lux | Cel nocturn ennuvolat i sense lluna
0.002 lux | Cel nocturn clar sense lluna amb resplendor del cel
0.27‐1.0 lux | Lluna plena en una nit clara
3.4 lux | límit fosc del crepuscle sota un cel clar
50 lux | llums de la sala d'estar familiar
80 lux | Passadissos, lavabos
100 lux | Dia molt fosc ennuvolat
320‐500 lux | Llum en una oficina
400 lux | Sortida o posta de sol en dies clars
1000 lux | Dia ennuvolat
10000‐25000 lux | Plena llum del dia (sol no directa)
32000‐100000 lux | Sol directe
Article de la Viquipèdia de Lux / CC BY

Ara que entenem una mica millor el funcionament del TEMT6000, es pot utilitzar en alguna cosa més interessant, com el control de llum exterior de la casa per que s'encengui i s'apagui automàticament, segons la llum ambient.

Sensor de humitat i temperatura, també hi ha una diversitat de sensors, individuals com el sensor de temperatura LM35 (KS0022 o el DS18B20 de millor qualitat (KS0023 o el que incorpora els dos sensors com el DTH11 (KS0034o el de més qualitat SHT31 (KS0348 que a més te comunicació I2C

LM35 | DS18B20 | DTH11 | SHT31

Aquests sensors poden estar ubicats en el interior de la casa i depenent dels valors es pot refrigerar o ventilar la casa es pot fer servir un ventilador adossat a una paret de la casa.

Com alternativa es pot utilitzar el ventilador (KS0168

El mateix sistema de sensors de humitat i temperatura es poden posar en el exterior de la casa, com una mini estació meteorològica.

Sistema d’alarma, amb diversos sensors es pot fer un sistema integrat d’alarma contra intrusió, foc, gas

El sensor de vibració (KS0037 |
sensor de cops (KS0024 | poden
detectar una intrusió.
El sensor de gas MQ‐2 (KS0040 |
ensor flama (KS0036 | poden
detectar alarma en una cuina.

## Programació de la casa

Com ja s’ha indicat aquest projecte es obert tant en la construcció i en el programari, sota una llicencia Creative Commons, on es poden aplicar diferents plaques i processadors amb moltes possibilitats. Però com sempre anirem pas a pas.

A més de preparar alguns exemples, aquesta maqueta precisament es per poder practicar programari i per tant qui vulgui “jugar” amb ella el millor es tenir la memòria buida i començar una programació des de cero, des de una part senzilla com encendre uns LED determinats, fer anar els servos per obrir o tancar una porta o finestra, o fer mesures amb els sensors. Però també depenent del nivell de la persona es pot fer un sistema complexa i global.

Es pot utilizar C per Arduino, Arduino Blocks o qualsevol altre IDE, però aquí veurem alguns exemples en Arduino Blocks, per la seva facilitat en l’aprenentatge i el suport a la placa STEMakers.

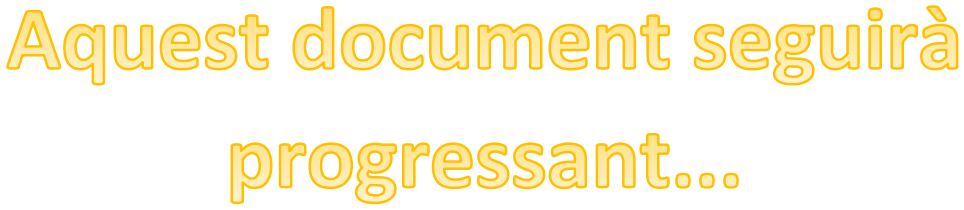
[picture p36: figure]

## Resum de peces impreses

- Parets Casa 4
- Marc i vidriera finestra gran 1 + 1
- Marc i vidriera finestra mitjana 1 + 1
- Marcs i vidrieres finestres petites 2 + 2
- Servos finestres + porta 5
- Porta + pom 1
- Teulada en dues meitats
- Suport RFID I2C 1
- Suport de 3 Polsadors 3
- Suport inclinat sensors 1
- Capsa CPU 1
- Tapa CPU 1

### Creative Commons Attribution-NoComercial-ShareAlike 4.0 International (CC BY-NC-SA 4.0)

## Agraïments

- Més que mai a Conchita, esposa i companya, per la seva comprensió amb els embolics em que em poso.
- Als components de Mechatronic Study, en Ramon Mayné i en César de la Rosa que han col∙laborat en idees i en la correcció dels texts.
- Als meus fills Isaac i Ferran Mayné, (Web, Github i altres punts)
- A les netes Júlia i Naia que m’han deixat els seus Playmobils per la casa.
- A l’arquitecte Carles Ferran, per els seus consells sobre la casa i la il∙luminació.
- En Josep Ballarà per la fusteria.
- En Ricard Gómez i l’Oriol Oreo del Punt Multimèdia del Ajuntament de Barcelona, per deixar‐me un espai en la Casa del Mig, per poder seguir muntant la maqueta quan a casa ja no hi cabia. A més, en Ricard ha realitzat l’estructura de programació en C per Arduino.
- En Pablo per que posi el codi QR per facilitar l’enllaç en la web de Github.
- En Toni Moreno i InnovaDidactic per la seva implicació en el projecte i la donació de material electrònic per la mateixa.
- A 3D Print BCN on he aprés molt.
- I també a una llarga llista de persones, que no les vull nombrar per no deixar‐me cap, que m’han recolzat en el projecte.

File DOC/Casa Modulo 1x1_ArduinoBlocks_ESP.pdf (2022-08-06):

1 | JORDI MAYNE ‐ 2022

# Casa domótica educativa

## Objetivo

Construir una maqueta de una casa educativa per aplicar domótica, midiendo parámetros de la naturaleza.

## Dinámica educativa

- Se pretende que sea Abierta, Didáctica, Evolutiva, Modulable, Flexible, y de bajo coste.
- La construcción de la maqueta está preparada para ser impresa con una impresora 3D convencional, pero se puede hacer con madera o cartón pluma, al ser modular permite adaptarla a las necesidades.
- Permite gestionar las luces a LED de colores, Sensores, Actuadores y otros elementos electrónicos para hacer la parte de domótica que se controlará con una placa ESP32 STEAMakers, aun que se puede hacer con Arduino, Microbit o hasta con una Raspberry ...

Como se podrá ver en toda la descripción, se quiere que se pueda explorar el máximo tipo de elementos y tecnologías.

## Descripción general

### Sensórica Externa

Midiendo nuestro entorno, como la Temperatura y Humedad coniental, Presión atmosférica, Luz, Rayos ultravioletas, Calidad del aire.

### Casa Domótica

Control del máximo de elementos usando tecnologías diversas como la Luz, Acceso, Ventilación, Calefacción, Motores.
Se puede detectar Gas, Fuego, Luz, Sonido, Humedad, Temperatura, Presencia (PIR, IR), Alarma.

### Comunicaciones

Dentro de un entorno sostenible las comunicaciones son necesarias si se gestionan bien como Bluetooth, Wifi, RFID.

## Realización del proyecto

- Descripción de cada parte de la maqueta.
- Selección de materiales y componentes.
- Desarrollo de cada parte.
- Construcción de la maqueta.
- Composición del control electrónico.
- Control global de la maqueta.

### Maqueta

La maqueta es una abstracción de una maqueta mucho más grande, creada para poder aplicar muchos más elementos y controles, pero dentro del mundo educativo pedía una casa más apropiada, por el tiempo disponible durante el curso, para aplicar los conceptos y llevarlos a cabo. Al ser modular permite adaptarla a las necesidades requeridas.

Casa Sostenible i Domótica • Las nuevas casas han de ser sostenibles, aprovechando todas las energías renovables que estén al

alcance (eólica, térmica, solar, hidráulica, geotérmica).
- Recogida del agua pluvial para reaprovecharla.
- Aprovechando la luz solar.
- Aislamiento.
- Control de residuos.
- Control domótico.

En esta maqueta por espacio no se pueden llevar a cabo todos estos puntos, pero algunos de ellos sí.

### Diseño de la maqueta de la casa

Para hacer esta maqueta he utilizado un proyecto mucho más grande https://github.com/maynej/Smart‐ Home y he realizado una abstracción, ya que su modularidad lo permite, utilizando un módulo 1x1 permite tener una maqueta tipo DIN A3 y a una escala 1:24 permite incluir y manipular los actuadores y sensores.

Se pueden escoger de la casa grande las paredes con los formatos que se quieran, para cubrir las necesidades para aplicar la tecnología. Se pueden imprimir en una impresora 3D convencional de 220x220mm. Estas paredes se pueden modificar para adaptarlas a un diseño propio, por eso se muestran tconién paredes sin ninguna puerta ni ventana por si se quiere desarrollar un diseño propio. Las paredes incorporan las fijaciones de los actuadores a las puertas, ventanas y en el tejado el alojamiento de las luces tanto interiores como exteriores y en esta maqueta el suporte para fijar los sensores. El tejado se puede quitar muy fácilmente para manipular los componentes.


Otros sopuertas como el módulo de RFID, pulsadores y otros sensores adicionales se pueden fijar en la base, así como el armario exterior (como si fuese para guardar la madera) que incluye la placa ESP32 STEAMakers, o Arduino Uno, un visualizador LCD y un teclado táctil.

### Identificación e unión de las paredes de la maqueta

- Para hacer la maqueta se ha buscado un sistema de identificación de cada pieza, marcando con una letra cada pared para una construcción guiada y más fácil.
- La unión entre las piezas se ha diseñado para que no se tenga que usar ninguna cola en la mayoría de las piezas. Esta unió se ha hecho a base de encajes y un pasador que las une.

Hay tres tipos de pared básicas donde se puede fácilmente implementar cualquier tipo de puerta, ventana, agujeros de fijación de otros elementos.



En este caso se usarán las paredes A1, C1, T1 y H1


Alternativamente la pared T1 se puede substituir por la T1_Fan que incorpora el alojamiento del ventilador de 40x40mm para simular la ventilación de la casa.


## Descripción del exterior de la Casa

- La casa es de tipo unifamiliar con un solo habitáculo con un tejado con techo practicable, que permite que sea accesible para manipular los diferentes componentes.
- Puerta de acceso a la casa. Timbre, y acceso con identificación por RFID.
- Iluminación de LED a color para el exterior, con detección de presencia y de luz diurna.
- Sensores en el tejado.

### Acceso a la casa

Como cualquier casa un pulsador servirá de timbre, también un lector RFID identificará y permitirá abrir la puerta con una tarjeta RFID válida.

- Timbre de llamada con pulsador (KS0029
- Lector RFID RC522 I2C (KS0205V2
- Puerta motorizada con un servomotor SG90 (KS0194

### Iluminación del exterior de la casa

Luces LED de color WS2812 y un sensor de proximidad PIR (KS0052con sensor de luz diurna para iluminar la puerta de entrada o las permanentes de noche desde el control central.

## Descripción del interior de la Casa

- Sistema de alarma
- Control de luz LED individualizado con control de intensidad de luz y de color
- Control de ventanas batientes motorizadas
- Control de puerta motorizada
- Control de ventilación

### Luz interior de la Casa

El control de la luz se hace tanto manualmente, como automático mediante sensores.

- LED + Sensor de movimiento (KS0052
- LED + Pulsador (KS0029
- LED + Sensor de voz (KS0035)
- LED + Sensor de luz ambiental TEMT6000 (KS0244 | o LDR (KS0028

### Ventilación

Un ventilador mueve el aire por toda la casa

- Temperatura LM35 (KS0022 | o DS18B20 (KS0023
- Humedad y Temperatura DTH11 (KS0034 | o SHT31 (KS0348
- Ventilador (KS0168

### Sistema de Alarma

Un sistema integrado de alarma contra intrusión, fuego, gas

- Sensor de vibración (KS0037

- Sensor de golpes (KS0024


- Sensor de gas MQ‐2 (KS0040
- Sensor llama (KS0036
- Zumbador pasivo (KS0019

### Pantalla y Teclado de control

- Pantalla LCD 2x16 I2C (KS0061, donde se podrá mostrar datos de la casa. También se podrá tener acceso desde un teléfono o “tablet”.
- Teclado táctil capacitivo | (KS0210KS0260
- Monitorización de datos de los sensores.
- Monitorización del control de acceso a la casa, sistema de seguridad.
- Monitorización de la ventilación.

### Sistema central de control

El control también está pensado abierto, si no ya no sería didáctico. Aunque se usará una ESP32 STEAMakers con formato Arduino UNO, está adaptado para utilizar Arduino UNO, o Microbit.

El software de estas plataformas permite utilizar diferentes lenguajes de programación, Scratch, C++ para Arduino, ArduinoBlocks.

- Arduino UNO, STEAMakers ESP32: Arduino Blocks, C++

### Alimentación

La maqueta al igual que muchas casas actuales que generen energía para el autoconsumo, necesitan también energía eléctrica adicional. La maqueta puede tener un generador de energía que pueden cargar unas pequeñas baterías, como puede ser una plataforma de células solar colocada en el tejado, pero normalmente se usará una fuente de energía a la red.

Planteamiento de la casa Esta construcción es minimalista, pero permite aplicar diferentes tecnologías para el control y se pueden

cambiar o añadir sensores.

## Planteamiento del control

- El control se podrá hacer a través de tareas individualizadas o agrupadas para ir progresando en el conocimiento de los dispositivos junto con el visualizador y teclado para mostrar sus funcionamientos.
- Muchas tareas se harán simuladas intentando reproducir al máximo su funcionamiento real.
- Los sensores básicos utilizados se podrán cambiar por otros similares o más sofisticados, está previsto que su acceso y cableado lo permite.

### Maqueta de la casa

La casa se ha formado con las siguientes piezas A, C1, T1, H1


### Ventanas batientes y Puertas motorizadas

- Las ventanas son batientes con movimiento a través de un servo‐motor.
- Las puertas también están motorizadas a través de un servo‐motor.
- Todas las puertas y ventanas tienen los anclajes en la pared para poner un servo‐motor.


### Tejado

El tejado está formado por una sola pieza, aunque está disponible en dos partes para poderlo imprimir con una base de 220x220mm. La parte inferior del tejado incorpora unos espacios donde irán instaladas las luces externas alrededor de la casa, así como la interna con LED a color del tipo tira de 8 LED WS2812. Con solo tres hilos se pueden controlar todos los LED.

En la parte superior se colocaran los sensores en unos suportes, también permite poner una cubierta semitransparente, para una entrada de luz solar, y para poder medir la temperatura interior y exterior del habitáculo.


Tejado y cubierta

### Sujeción de las paredes a la base

Todas las paredes tienen agujeros para anclarlas a la base de madera de la casa.


La base de madera puede ser de 5mm, se acota toda la maqueta y se mecaniza o se puede hacer con corte a láser, se incluye el fichero svg. Se puede añadir en el dibujo svg el logo o nombre del usuario.


Los cuatro puntos de la casa fijan la estructura, los agujeros ovalados son para el paso de los cables de los servomotores por debajo de la base hasta el paso rectangular para entrar en la caja del control central.

Una vez fijada la estructura de la casa, se puede continuar trabajando con el resto de la casa, colocando los marcos de las puertas, ventanas, ....


En el tablero base de la casa se fijan cuatro separadores de goma de 20 mm de altura, suficiente para dejar pasar los cables.

El tejado semitransparente se puede hacer con una hoja de plástico a partir de 0,75mm de grueso para que tenga un poco de consistencia. Las ventanas también pueden tener los cristales, pero con plástico transparente.


### Montaje electrónico

Para empezar con el sistema electrónico se puede hacer el conexionado de las luces de LED multicolor WS2812B en la parte inferior del tejado. Se usarán tres hilos (positivo +5V, negativo (gnd) y datos) con tres colores bien diferenciados para no hacer ningún error de conexión. Se pueden fijar los hilos trenzando en forma de espiral y se pueden sujetar con tubo termo‐retráctil.

Las soldaduras han de estar bien hechas y que no se produzcan cruces en las conexiones, hay que hacer una revisión visual y una prueba de funcionamiento antes de colocarlo en los encajes del tejado.


Una vez que se ha realizado el cableado y revisado, se puede colocar en la hendidura correspondiente y se fija con un poco de cola termo‐fusible.


## Planteamiento del control central

Tal como se ha expuesto al principio de este documento, el control central se podrá hacer a través de tareas individualizadas o agrupadas para facilitar una programación, primeramente, por partes para facilitar el uso de un hardware sencillo. De esta manera se pueden establecer funcionalidades básicas hasta las más complejas, y funcionalidades futuras.

### Control central

El control central está planteado utilizando la placa ESP32 STEAMakers, basada en el controlador ESP32 Plus, compatible con el formato Arduino UNO, fabricada por Keyestudio, y ha sido desarrollada conjuntamente con el equipo de Innova Didàctic.

La primera cosa que sorprende al ver esta placa es la cantidad de pins disponibles a parte de los conectores que incorporan todas las placas formato Arduino, que corresponden a 12 entradas/salidas digitales, 4 entradas analógicas, 1 canal serie Tx/Rx y 5 conectores I2C, todos con alimentación, y un zócalo para memorias µSD en la parte posterior.


Pero hay más detalles, un conmutador de 3.3V a 5V para algunos pins de alimentación y un shunt en la alimentación para medir la corriente.

El procesador ESP32 de 32 bit, es un sistema de doble núcleo con dos CPU (Unidad Central de Proceso) con arquitectura Harvard Xtensa LX6. Tota la memoria interna, la memoria externa y los periféricos se encuentran en el bus de datos y/o en el bus de instrucciones de estas CPU. Con algunas excepciones menores, la asignación de direcciones de las dos CPU es simétrica, lo que significa que utilizan las mismas direcciones para acceder a la misma memoria. Diversos periféricos del sistema pueden acceder a la memoria interna mediante DMA. Las dos CPU se denominan "PRO_CPU" (para computar los protocolos) y "APP_CPU" (para computar la aplicación), pero para la mayoría de propósitos, las dos CPU son utilizables para cualquier tarea. Más adelante se verá en profundidad la estructura del núcleo.

### Tareas individualizadas

En este apartado se mostrarán las tareas que se pueden realizar para trabajarlas individualmente y su hardware asociado.

### Control de las luces de la casa

Las luces de la casa son de LED del tipo RGB WS2812 (denominados Neopixel) en formato de tira de 8 LED, se pueden encender individualmente con el color y con la intensidad de luz que se quiera (por programa), y solo con un hilo y dos de alimentación. Esto permite hacer escenarios diferentes del exterior de la casa, hay cuatro grupos, uno para cada pared. También hay una tira en el interior para poder crear un ambiente de luz más cálida o más blanca.
Estas luces pueden ser automáticas como el caso de las luces exteriores, con un sensor de luz ambiente, o a través de pulsadores mecánicos o táctiles. También se podrá comandar alguna luz con sensor de presencia. Por tanto, es una instalación para un control muy flexible.

Primero de todo hace falta enumerar cada punto de luz de la casa para preparar la programación. Como que son grupos de 8 LED y el primer corresponde a la fachada frontal (L1, L2, L3, L4, L5, L6, L7, L8). Si se usan más grupos serán: L9‐L16 para la fachada izquierda, L17‐L24 fachada posterior, L25‐32 fachada derecha y L33‐40 para la luz interior. También los pulsadores, para encender y apagar las luces interiores LINT y las luces exteriores LEXT.


Se puede crear una tabla para tener todos los componentes:

Descripción | Actuador | Pin STEAMakers | Pulsador | Pin STEAMakers
LED frontal | L1‐L8 | io12 | LEXT | io26
LED izquierda | L9‐L16 | io12 | LEXT | io26
LED posterior | L17‐L24 | io12 | LEXT | io26
LED derecha | L25‐L32 | io12 | LEXT | io26
LED interior | L33‐L40 | io13 | LINT | io26

Es decir, se usan dos pins para los pulsadores io12, io13, y para todos los LED solo el pin io26. Ahora podemos añadir el control de servos de puerta y ventanas.

### Control de los servos puerta y ventanas

Los servos abren o cierran la puerta y ventanas, también hace falta enumerar cada uno. Puerta D1, ventana frontal W1, ventana izquierda W2, ventana posterior W3, ventana derecha W4.

Se puede crear una tabla para tener todos los componentes conectados a la placa STEAMakers:

Descripción | Actuador | Pin STEAMakers | Pulsador | Pin STEAMakers
LED frontal | L1‐L8 | io12 | LEXT | io26
LED izquierda | L9‐L16 | io12 | LEXT | io26
LED posterior | L17‐L24 | io12 | LEXT | io26
LED derecha | L25‐L32 | io12 | LEXT | io26
LED interior | L33‐L40 | io13 | LINT | io26
Servo Puerta frontal | S_D1 | io14 | D1 | io19
Servo Ventana frontal | S_W1 | io27 | W1 | io23
Servo Ventana izquierda | S_W2 | Io16 | W2 | io05
Servo Ventana posterior | S_W3 | io17 | W3 | io13
Servo Ventana derecha | S_W4 | io25 | W4 | io12
LED frontal | L1‐L8 | io26 | LEXT | io18
LED izquierda | L9‐L16 | io26 | LEXT | io18
LED posterior | L17‐L24 | io26 | LEXT | io18
LED derecha | L25‐L32 | io26 | LEXT | io18
LED interior | L33‐L40 | io26 | LINT | ?

¿Qué ha pasado? ..., que hemos conectado todos los componentes menos uno, el pulsador de activación de la luz interior (LINT), no queda ninguna entrada/salida digital libre...

Aún que todos los LED tanto exteriores como interiores solo usan un sol pin (io26), los demás 6 pulsadores nos ocupan la totalidad de entrades digitales y aún nos falta uno.

Las soluciones posibles son diversas, o usar menos ventanas o añadir circuitos que nos resolverán este problema.


### Expansión de entradas y salidas en un Arduino

Como que se necesiten muchas entrades de pulsadores, hay que plantear utilizar placas Arduino que tienen más entradas/salidas o varias placas Arduino conectadas entre sí, cosa que no es la solución más adecuada. Es mejor colocar un expansor de entrades/salidas con un módulo expansor vía dos hilos I2C.

PCF8574 es un módulo expansor de 8 canales digitales de entrada/salida con comunicación I2C hacia el microcontrolador, por defecto al alimentar el circuito son entrades digitales (P0 a P7), funciona entre 2,5 y 6V, incorpora 3 puentes (A0 a A2) para configurar la dirección I2C (desde 0x20 a 0x27 si están a ‐), tiene dos pins de comunicación típicas de I2C, SDA (datos), SCL (reloj) y alimentación.

Se encuentran diferentes formatos de módulo, este de color azul permite
expandir a más placas PCF8574 encadenando diversos módulos para tener
aún más entradas/salidas digitales.

Cada módulo adicional se configura con una dirección I2C diferente, se selecciona con los puentes de cada módulo.

Este módulo con A0, A1 y A2 con el puente a 0, corresponde a la dirección 0x20

Se pueden encadenar diversos módulos PCF8574 de la manera siguiente y cambiando un puente de direccionamiento.

Así quedará el montaje, liberando 6 pins de entrada de la placa STEAMakers, y aún quedan dos pins libres en el módulo PCF8574.


Si se quieren liberar más pins se puede hacer añadiendo otro módulo I2C PCA9685 que soporta hasta 16 servomotores controlados vía I2C. Dispone de pins para conectar adecuadamente los servomotores, las direcciones I2C van desde 0x40 hasta 0x7F soldando los puentes (A0...A5), entrega 16 salidas PWM de 12 bits, se alimenta a 5V, y las líneas SDA y SCL de I2C son compatibles 3V3 o 5V.

A parte de liberar pins, se ha de tener en cuenta que los servomotores tienen
un consumo “elevado”, sobre los 200mA que circula por dentro del circuito procesador de Arduino y si además liberamos esta corriente, siempre es mejor, en este caso podemos programar que las ventanas se abren a la vez, para airear la casa, o cerrarlas para evitar que entre frío, 200mA multiplicado por 4 ventanas son 0,8A que circularían por el circuito.

Servomotores SG90: Un servomotor, también denominado servo, es un motor DC con la capacidad de poner su eje en una posición o ángulo determinado, internamente tiene una caja de engranajes reductora que hace aumentar el par motor y reducir la velocidad, un
potenciómetro está encargado de sensar la posición del eje y junto con una electrónica
forman un control de lazo cerrado.

Hay diferentes tipos de servomotores, el más utilizado es el SG90 que es suficiente para la mayoría de aplicaciones. Funciona entre 3 y 7.2V, tiene un par motor entre 1 y 1.6 kg/cm. Otros tienen par motor más grandes llegando hasta 15 kg/cm.

Utilizando el módulo PCA9685 libera 5 pins más, digitales. Así queda el esquema eléctrico.


Vamos añadiendo más componentes, visualizador y teclado. Una vez más se ha escogido dos módulos con comunicación I2C visualizador LCD 1602 (KS0061 y teclado táctil TTP229 (KS0260.


Con estos componentes no se usa ningún pin digital.

Para alojar los módulos STEAMakers, PCF8574 y PCA9685, así como el visualizador LCD 1602 y el teclado TTP229, se ha creado un armario para el exterior de la casa. Se podrán utilizar todos estos módulos o no, pero el armario está preparado para fijarlos. La tapa puede alojar el teclado TTP229 (KS0210 conector rectangular 6 pin y 3 agujeros de sujeciónKS0260 conector 4 pin en línea más útil para usar los cables I2C y 4 agujeros de sujeciónla diferencia entre ellas es los agujeros de anclaje y el tipo de conector, pero la funcionalidad es la misma.


También para el lector de RFID se ha escogido el módulo RC522 I2C (KS0205V2 se ha creado el soporte en posición inclinado para acercar la tarjeta (TAG) de una forma cómoda.

Pero aún se pueden utilizar más componentes, como un zumbador, ventilador, sensores,... por eso se han creado unos soportes para este componente, 5 están en el tejado de la casa, aquí se exponen algunos, pero será el usuario quien determinará cuales y donde los ubicará, dependiendo de las funcionalidades que se quieran dar.

Aquí se pueden ver los diferentes tipos de soportes hasta 3 componentes, y en el repositorio https://github.com/maynej/Smarthome‐1x1‐Module se pueden encontrar de 2, 3 y 4 componentes cada uno. Keyestudio facilita bastante con la uniformidad física de las placas de cada componente.


Zumbador (KS0019(Buzzer en inglés) es un transductor electroacústico que produce un sonido como si fuera un altavoz, aunque en una calidad menor. Sirve como un mecanismo
de señalización o aviso, y si se utiliza en múltiples sistemas se puede que emita sonidos
diferentes según la frecuencia aplicada.

Puede servir, como timbre de la puerta, alarma de intrusión, u otro tipo de alarma de los diferentes sensores que usamos.

Sensores de presencia o movimiento, hay diversas maneras de detectar “presencia”, lo primer es conocer los diferentes tipos y ver que queremos detectar y donde. Es puede hacer con IR, ultrasonidos, PIR, láser, radar, mecánico, sonido.

IR consisten en un emisor y un receptor de IR actúan por rebote (KS0051 es bastante
direccional 35 grados, el alcance es de 2 a 40 cm (ajustable con potenciómetros), la
influencia de los rayos del sol va en contra.

Ultrasonidos, se trata de emitir un sonido a 40kHz (no audible para los humanos) y recibir por rebote este sonido, midiendo el tiempo que tarda se puede determinar la distancia hasta el objecto. No es tan direccional (15 grados), el alcance es grande, entre 2 y 5m. (KS0206
Las aplicaciones en una casa se pueden usar para medir el nivel de líquido en un
depósito.

PIR (Infra‐Rojos Pasivo) es de un material piroeléctrico que cambia sus propiedades según las emisiones IR captadas que pasan a través de una lente de Fresnel, que es una semiesfera que concentra estas emisiones en un solo punto. Detectan objetos que emiten calor (como los cuerpos humanos y animales) el alcance es más grande hasta 3‐4 metros a 25ºC, y no es direccional, 100 grados. Es el que se usará para detectar cuando una persona se acerca a la puerta y se enciende la luz de la puerta. (KS0052

Láser, realmente nos referimos a los llamados TOF (Time of Flight), son de última generación y miden el tiempo en que un pulso de láser sale desde el emisor, rebota en el objeto y vuelve al receptor, se cuenta el tiempo y se consiguen medir la distancia con mucha precisión. Es muy direccional, el alcance puede llegar, dependiendo del modelo, hasta a 2m (VL53L0X). Detecta cualquier tipo de objeto. En una casa se podría usar para detectar que una persona se acerca al interfono y se pone el sistema en marcha (por ejemplo, el vídeo portero).

Mecánico, podría ser un microrruptor bajo una madera o en una puerta(KS0021
Sensor de sonido, se puede utilizar el sonido de la voz para activar una luz, | (KS0035)

Sensores de luz, hay una diversidad de sensores de luz, aquí nos centramos en el más básico
basado en una LDR (Resistencia que Depende de la Luz) (KS0028 y el más completo y aconsejable, el sensor de luz ambiental TEMT6000 (KS0244.

El sensor TEMT6000 que solo detecta la presencia amalgamada de luz con longitudes de onda en el rango entre 390 a 700 nm, en otras palabras, no captará infrarrojos, ultravioletas o ninguna otra luz que no podamos ver directamente. Es un sensor analógico que es sensible al espectro visible y se usa en muchos aparatos como “smartphones”, “tablets”, cámaras… y está adaptado a la respuesta del ojo humano respecto a la luz. Tiene un ángulo de 60 grados y se alimenta a 5V.

Aquí se muestra una tabla de la iluminación típica de fuentes comunes de luz visible:

Iluminación | Superficies iluminadas por
0.0001 lux | Cielo nocturno nublado y sin luna
0.002 lux | Cielo nocturno claro sin luna con resplandor del cielo
0.27‐1.0 lux | Luna plena en una noche clara
3.4 lux | Límite obscuro del crepúsculo bajo un cielo claro
50 lux | Luces de la sala de estar familiar
80 lux | Pasillos, lavabos
100 lux | Día muy obscuro nublado
320‐500 lux | Luz en una oficina
400 lux | Salida o puesta de sol en días claros
1000 lux | Día nublado
10000‐25000 lux | Plena luz de día (sol no directo)
32000‐100000 lux | Sol directo
Artículo de la Wikipedia de Lux / CC BY

Ara que entendemos un poco mejor el funcionamiento del TEMT6000, se puede utilizar en alguna cosa más interesante, como el control de la luz exterior de la casa para que se encienda y se apague automáticamente, según la luz ambiente.

Sensor de humedad y temperatura, también hay una diversidad de sensores, individuales como el sensor de temperatura LM35 (KS0022 o el DS18B20 de mejor calidad (KS0023 o el que incorpora los dos sensores como el DTH11 (KS0034o el de mayor calidad SHT31 (KS0348 que además tiene comunicación I2C

LM35 | DS18B20 | DTH11 | SHT31

Estos sensores pueden estar ubicados en el interior de la casa y dependiendo de los valores se puede refrigerar o ventilar la casa, con un ventilador adosado a una pared de la casa.

Como alternativa se puede utilizar el ventilador (KS0168

El mismo sistema de sensores de humedad y temperatura se pueden poner en el exterior de la casa, como una mini estación meteorológica.

Sistema de alarma, con diversos sensores se puede hacer un sistema integrado de alarma contra intrusión, fuego, gas

El sensor de vibración (KS0037 | y/o el sensor de golpes (KS0024
podemos detectar una intrusión.
El sensor de gas MQ‐2 (KS0040 | el sensor llama (KS0036)poden
detectar alarma en una cocina.

## Programación de la casa

Como ya se ha indicado este proyecto es abierto tanto en la construcción y en la programación, bajo una licencia Creative Commons, donde se pueden aplicar diferentes placas y procesadores con muchas posibilidades. Pero como siempre ser irá paso a paso.

Además de preparar algunos ejemplos, esta maqueta precisamente es para poder practicar programación y por tanto quien quiera “jugar” con ella, lo mejor es tener la memoria vacía y empezar una programación desde cero, desde una parte sencilla como encender unos LED determinados, hacer funcionar los servos para abrir o cerrar una puerta o ventana, o hacer medidas con los sensores. Pero también dependiendo del nivel de la persona se puede hacer un sistema complejo y global.

Se puede utilizar C para Arduino, Arduino Blocks o cualquier otro IDE, pero aquí veremos algunos ejemplos en Arduino Blocks, por su facilidad en el aprendizaje y en el soporte a la placa STEMakers.

## Resumen de piezas impresas

- Paredes Casa 4
- Marcos y cristalera de ventana grande 1 + 1
- Marco y cristalera ventana mediana 1 + 1
- Marcos y cristaleras ventanas pequeñas 2 + 2
- Servos ventanas + puerta 5
- Puerta + pomo 1
- Tejado en dos mitades
- Soporte RFID I2C 1
- Soporte de 3 pulsadores 3
- Soporte inclinado sensores 1
- Caja CPU 1
- Tapa CPU 1

### Creative Commons Attribution-NoComercial-ShareAlike 4.0 International (CC BY-NC-SA 4.0)

## Agradecimientos

- Más que nunca a Conchita, esposa y compañera, por su comprensión con los embrollos em que me pongo.
- A los componentes de Mechatronic Study, Ramon Mayné y en César de la Rosa que han colaborado en ideas y en la corrección de los textos.
- A mis hijos Isaac y Ferran Mayné, (Web, Github y otros puntos)
- A las nietas Júlia y Naia que me han dejado sus muñecos Playmobil para la casa.
- Al arquitecto Carles Ferran, por sus consejos sobre la casa y los escenarios de iluminación.
- A Josep Ballarà por la madera.
- Ricard Gómez y Oriol Oreo del Punt Multimèdia de l’Ajuntament de Barcelona, per dejarme un espacio en la Casa del Mig, para poder seguir montando la maqueta cuando en casa ya no cabía.
- A Pablo para que ponga el código QR para facilitar el enlace en la web de Github.
- A Toni Moreno e InnovaDidactic por su implicación en el proyecto y la donación de material electrónico para la misma.
- A 3D Print BCN donde he aprendido mucho.
- I también a una larga lista de persones, que no las quiero nombrar para no dejarme ninguna, que me han apoyado en el proyecto.

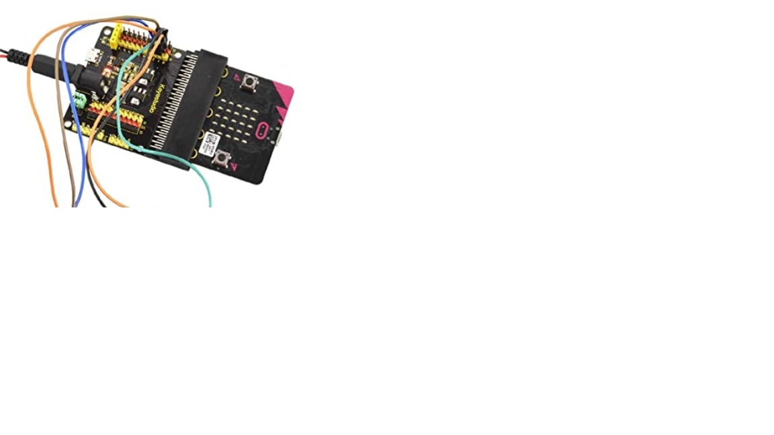
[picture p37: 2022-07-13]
Imatges/MicroDomotic.jpg

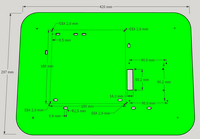
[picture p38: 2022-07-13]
Imatges/BaseFustaSVG.png

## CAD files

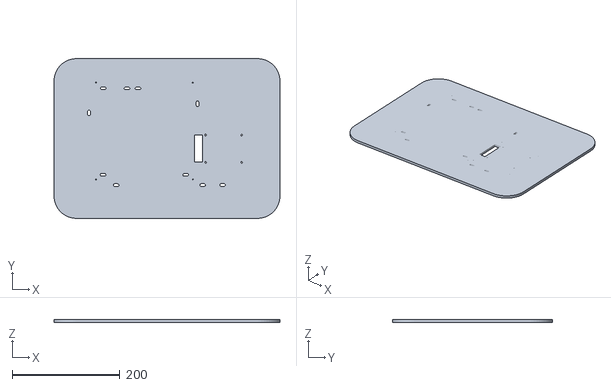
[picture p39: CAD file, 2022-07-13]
STL/BaseFusta.stl
420.0 x 296.9 x 5.10

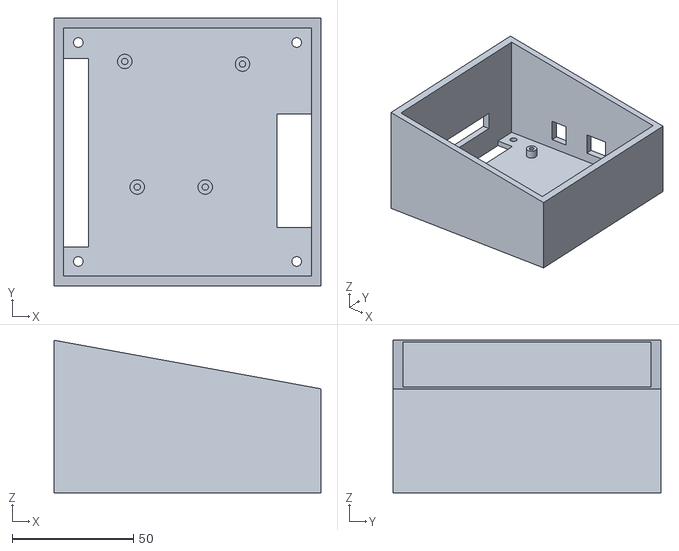
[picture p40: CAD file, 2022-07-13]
STL/CPU/CalaixCPU.stl
110.0 x 110.2 x 62.9

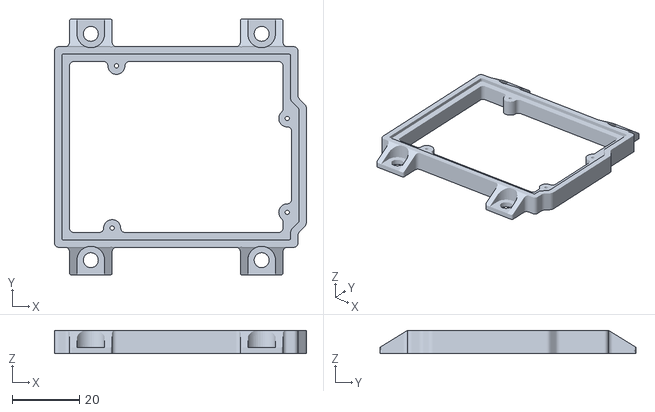
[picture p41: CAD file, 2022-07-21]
STL/CPU/SuportCPU_formatUNO/SuportArduinoUNO.stl
74.9 x 76.2 x 6.99

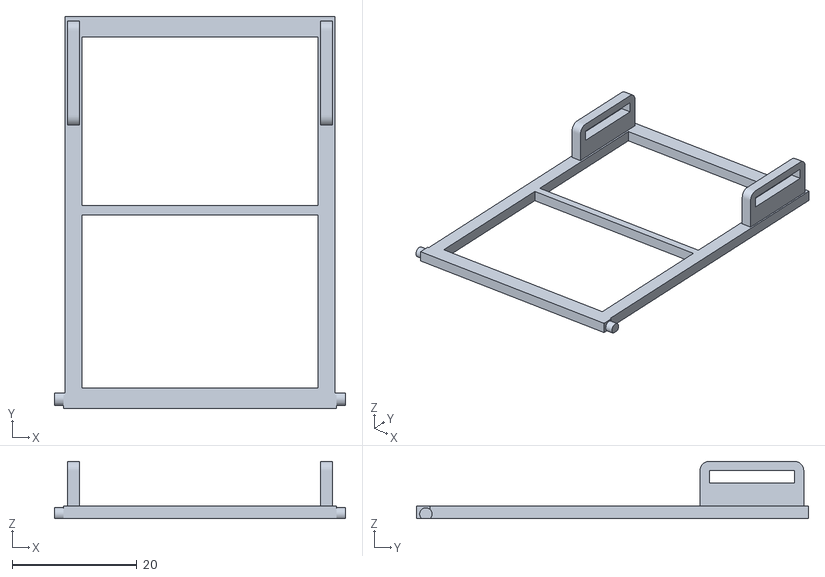
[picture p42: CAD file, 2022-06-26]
STL/Finestres/VidrieraMitjana.stl
46.6 x 62.8 x 9.18

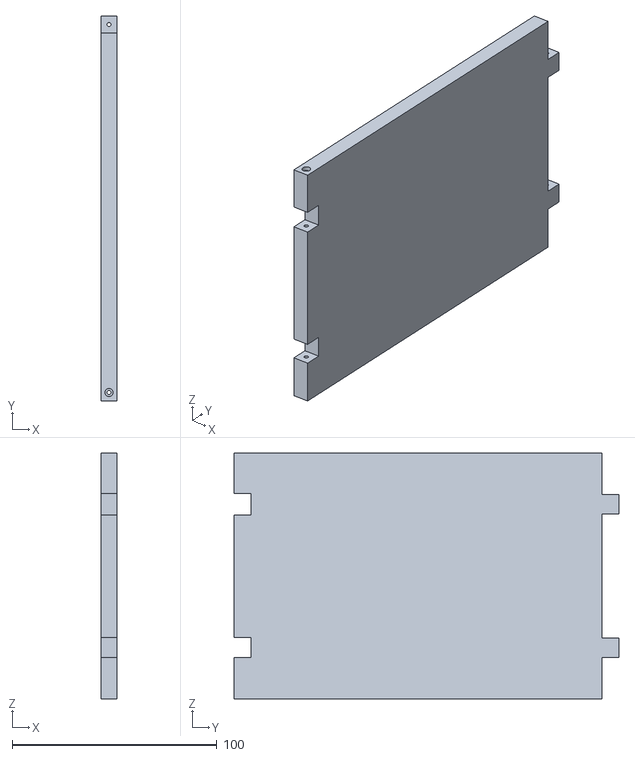
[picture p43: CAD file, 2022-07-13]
STL/Parets/ParetsSolidesOpcionals/ParetBase_Mascle_Femella.stl
8.00 x 188.0 x 120.0

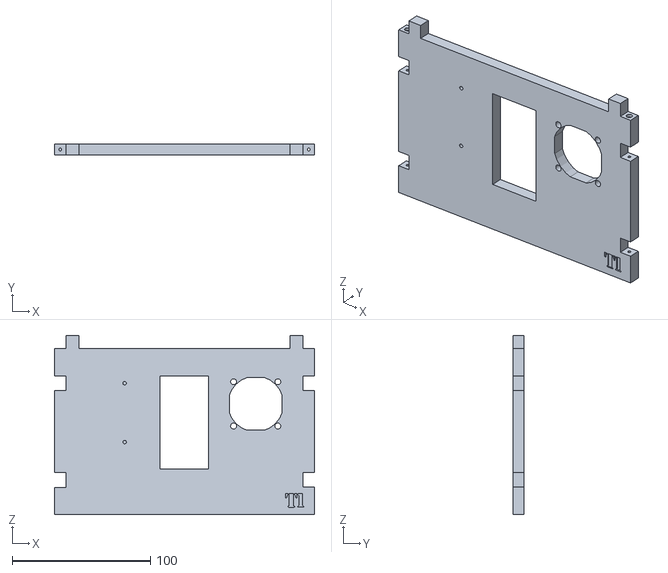
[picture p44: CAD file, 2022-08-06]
STL/Parets/ParetT1_Fan.stl
188.0 x 8.00 x 129.5

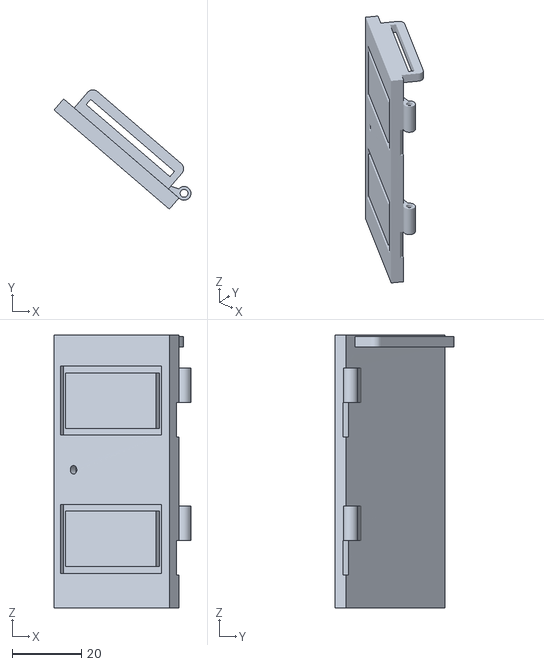
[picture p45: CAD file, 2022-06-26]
STL/Porta/Porta_Dreta.stl
39.6 x 34.5 x 79.0

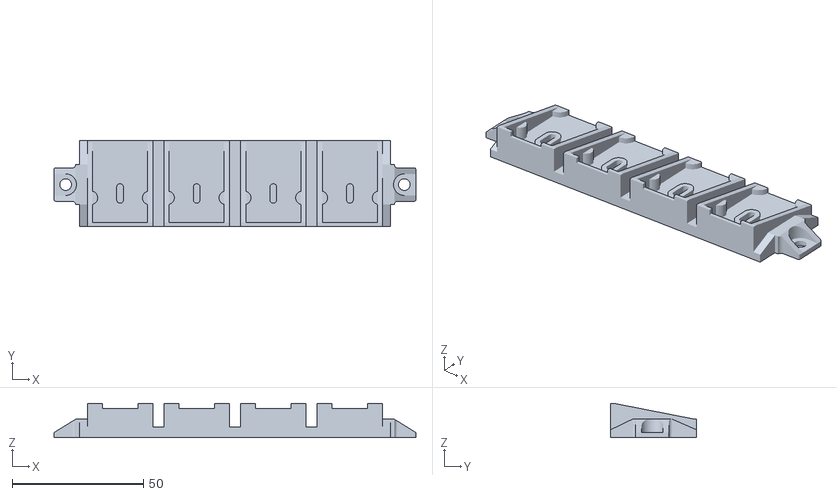
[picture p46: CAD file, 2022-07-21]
STL/SuportsModuls/Suport1forat/Suport1forat_4.stl
138.0 x 32.6 x 13.0

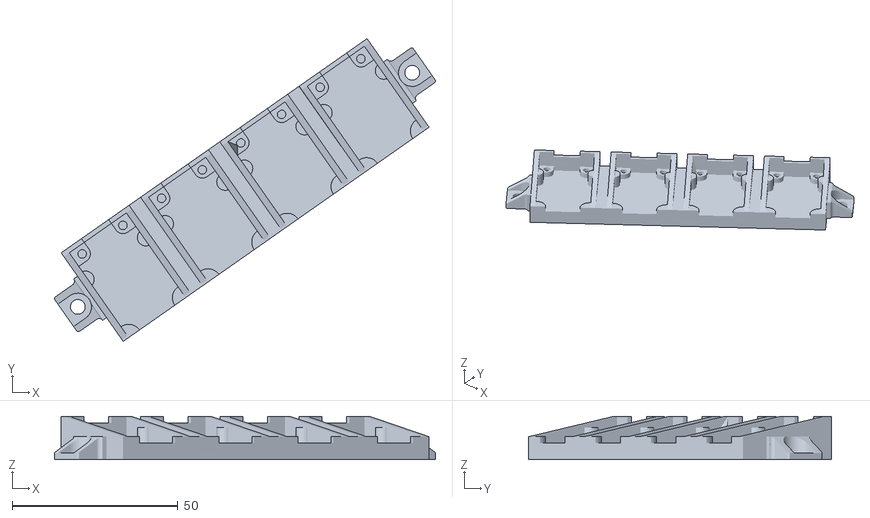
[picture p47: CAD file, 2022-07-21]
STL/SuportsModuls/Suport2forats/Suport2forats_4.stl
114.9 x 91.3 x 13.0

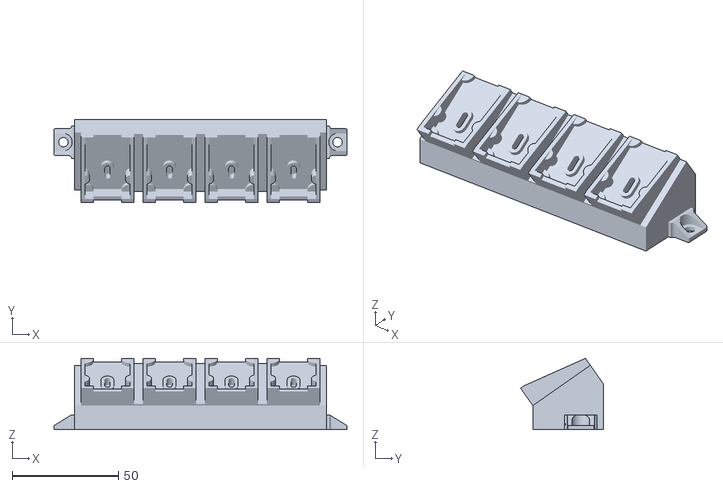
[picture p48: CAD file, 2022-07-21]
STL/SuportsModuls/SuportInclinat1forat/SuportInclinat1forat_4.stl
138.0 x 39.0 x 33.6

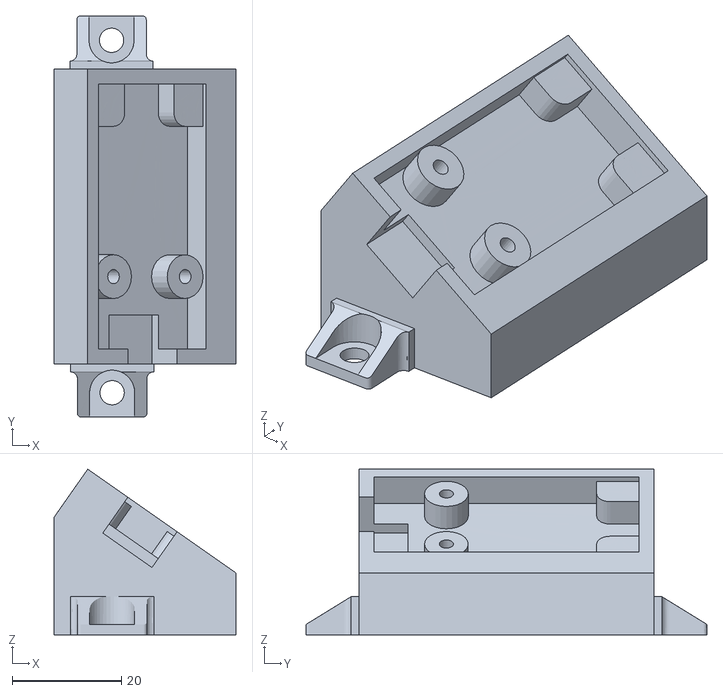
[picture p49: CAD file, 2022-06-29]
STL/SuportsModuls/SuportRFID.stl
33.3 x 73.4 x 30.3

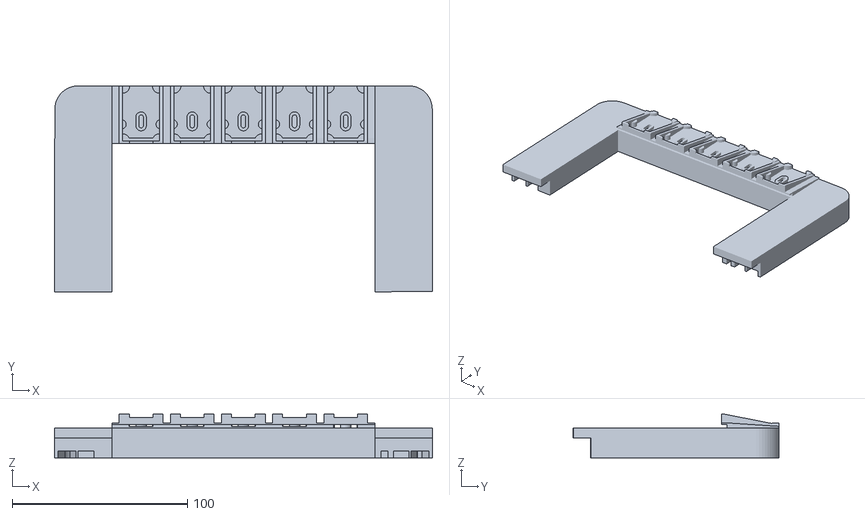
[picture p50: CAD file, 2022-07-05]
STL/Teulada/TeuladaPartida1.stl
215.8 x 117.8 x 25.0

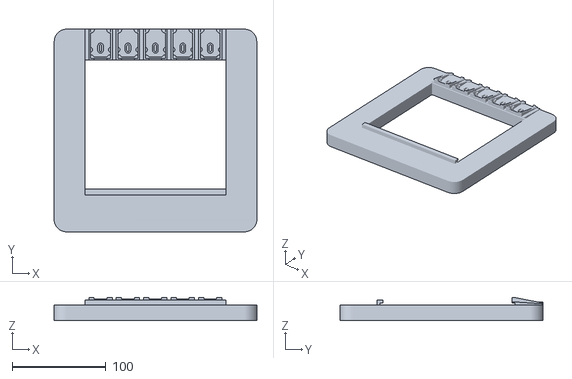
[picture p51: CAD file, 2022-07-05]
STL/Teulada/TeuladaSencera/TeuladaSencera.stl
216.0 x 215.8 x 25.0

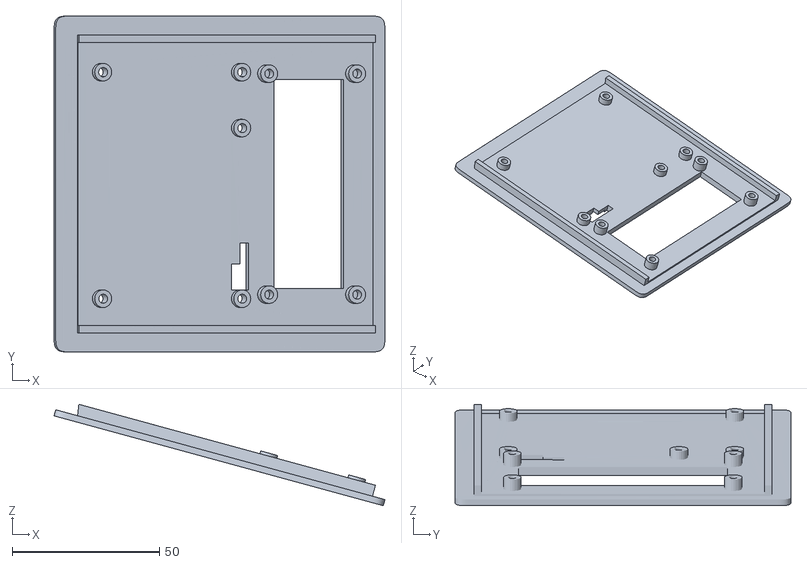
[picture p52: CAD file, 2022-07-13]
STL/CPU/TapaCPU_LCD_Touch.stl
112.5 x 114.2 x 34.5

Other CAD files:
STL/Finestres/VidrieraGran.stl
STL/Parets/ParetH1.stl
STL/Parets/ParetsSolidesOpcionals/ParetBase_Femella_Femella.stl
STL/Porta/MarcPorta.stl
STL/Finestres/MarcFinestraGran.stl
STL/Finestres/MarcFinestraMitjana.stl
STL/Finestres/MarcFinestraPetita.stl
STL/Finestres/VidrieraPetita.stl
STL/Parets/ParetA1.stl
STL/Parets/ParetC1.stl
STL/Parets/ParetT1.stl
STL/Parets/ParetsSolidesOpcionals/ParetBase_Mascle_Mascle.stl
STL/Porta/PomPorta.stl
STL/SuportsModuls/Suport1forat/Suport1forat_2.stl
STL/SuportsModuls/Suport1forat/Suport1forat_3.stl
STL/SuportsModuls/Suport2forats/Suport2forats_2.stl
STL/SuportsModuls/Suport2forats/Suport2forats_3.stl
STL/SuportsModuls/SuportInclinat1forat/SuportInclinat1forat_2.stl
STL/SuportsModuls/SuportInclinat1forat/SuportInclinat1forat_3.stl
STL/Teulada/TeuladaPartida2.stl
